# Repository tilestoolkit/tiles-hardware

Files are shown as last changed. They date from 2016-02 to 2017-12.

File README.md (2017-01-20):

# IoT Squares 

Squares are tiny stickers with electronics that give superpowers to everyday objects. They implement a set of physical interaction primitives.

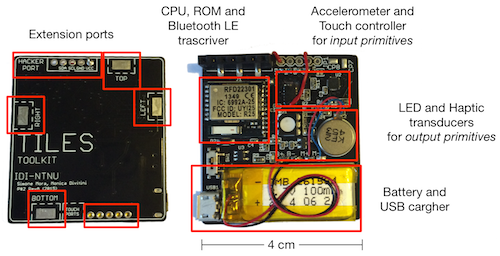
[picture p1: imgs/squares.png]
Squares modules


Squares are part of Tiles, an inventor toolbox to support the design and making of interactive objects for learning and play. For more information tilestoolkit.io

This work is licensed under a [Creative Commons Attribution-ShareAlike 4.0 International License](https://creativecommons.org/licenses/by-sa/4.0/).

## Prototypes History

### Prototype 1
Designed by Norwegian Creation, March 2015

### Prototype 2 Rev A
Designed by Simone Mora, PCB manufacturing and partial assembly from Seeedstudio Fusion Service, November 2015
#### Note: 
* Bug in board design, shortcut between VDD and SDA lines

### Prototype 2 Rev B
Designed by Simone Mora, never produced.
#### Note: 
* Fixed Rev A bugs

### Prototype 2 Rev C
Designed by Simone Mora, PCB manufacturing and partial assembly from Seeedstudio Fusion Service, April 2016
#### Note: 
* Removed touch controller MPR121
* Swapped components no longer available from Seed CPL

### Prototype 2 Rev D
Designed by Simone Mora, PCB manufacturing and partial assembly from Macrofab, November 2016
#### Note:
* Moved from SMD to DIP programming header
* Swapped components not available on Macrofab common parts library
* Added Seeed GROVE I2C connector

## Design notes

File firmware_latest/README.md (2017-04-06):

# Tiles DEVICE

## Notes
- When programming a Square Prototype 2 Rev D (RED Square) the ON/OFF switch must be put on OFF.
- Set in the code the type of Square module you have. For RFDUINO-shield-based modules set the *IS_SHIELD* variable on *TRUE*. For Prot#2 RevD module set the *COMMON_ANODE* to *true*

## API for Tiles DEVICE
### Events
| ID | Name | Parameter 1 | Parameter 2 | Implemented | Comments |
|----|---|---|---|---|---|
|Tile_XX | tap | single, double |  | yes | |
| | tilt | | | yes| |
| | shake  | | | yes| |
| | rotate | clock, c_clock | | yes | clockwise and counter clockwise |
| | drop | | | no | free fall event |
| | lift | | | no |  |
| | proximity | | | no | to be implemented with capacitive touch |

#### Example

Event generated when one Tiles is tapped twice
```javascript
"Tile_XX,tap,double"
```

### Commands
<table>
    <tr>
        <th>ID</th>
        <th>Name</th>
        <th>Parameter1</th>
        <th>Parameter2</th>
        <th>Implemented</th>
        <th>Comments</th>
    </tr><tr>
        <td>Tile_XX,</td>
        <td>led,</td>
        <td>off</td>
        <td>-</td>
        <td>yes</td>
        <td></td>
    </tr><tr>
        <td></td>
        <td></td>
        <td>on,</td>
        <td>red, green, blue, white</td>
        <td>yes</td>
        <td></td>
    </tr><tr>
        <td></td>
        <td></td>
        <td>on,</td>
        <td>{HEX}</td>
        <td>yes</td>
        <td>example: FF00FF=pink</td>
    </tr><tr>
        <td></td>
        <td></td>
        <td>blink,</td>
        <td>red, green, blue, white</td>
        <td>yes</td>
        <td></td>
    </tr><tr>
        <td></td>
        <td></td>
        <td>blink,</td>
        <td>{HEX}</td>
        <td>yes</td>
        <td></td>
    </tr><tr>
        <td></td>
        <td></td>
        <td>fade,</td>
        <td>red, green, blue, white</td>
        <td>only blue color implemented</td>
        <td></td>
    </tr><tr>
         <td></td>
         <td>haptic,</td>
         <td>long</td>
         <td>-</td>
         <td>yes</td>
         <td>long vibration</td>
     </tr><tr>
         <td></td>
         <td></td>
         <td>burst</td>
         <td>-</td>
         <td>yes</td>
         <td>short vibration</td>
     </tr>
</table>

#### Example
Turn on LED with color RED on 'Tile_XX' send command:
```javascript
"Tile_XX,led,on,red"
```
or use HEX
```javascript
"Tile_XX,led,on,FF0000"
```

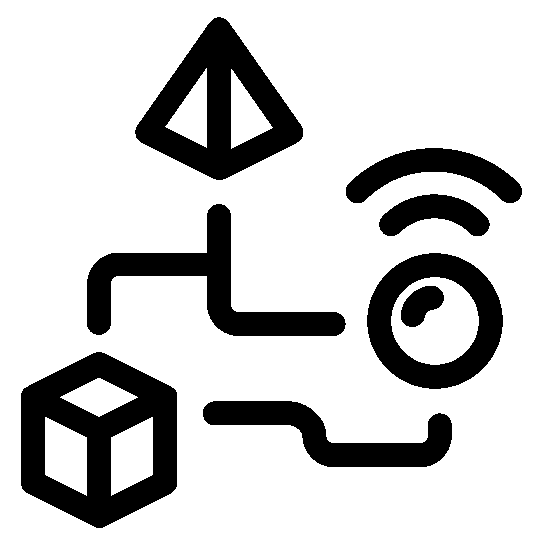
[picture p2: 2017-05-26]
Dock P1RB/imgs/noun_143916_cc.bmp

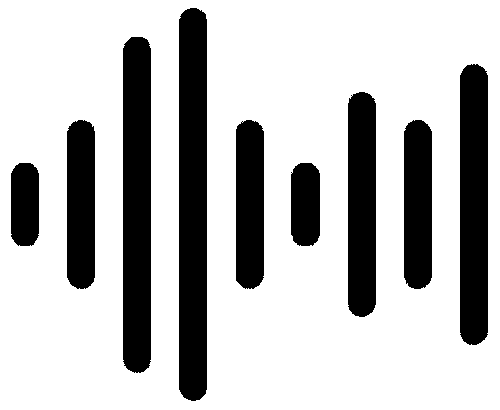
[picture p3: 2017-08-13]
Prototype 3 RevB/imgs/digi.bmp

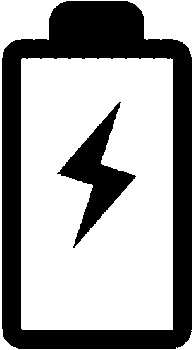
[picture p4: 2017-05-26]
Dock P1RB/imgs/battery.bmp

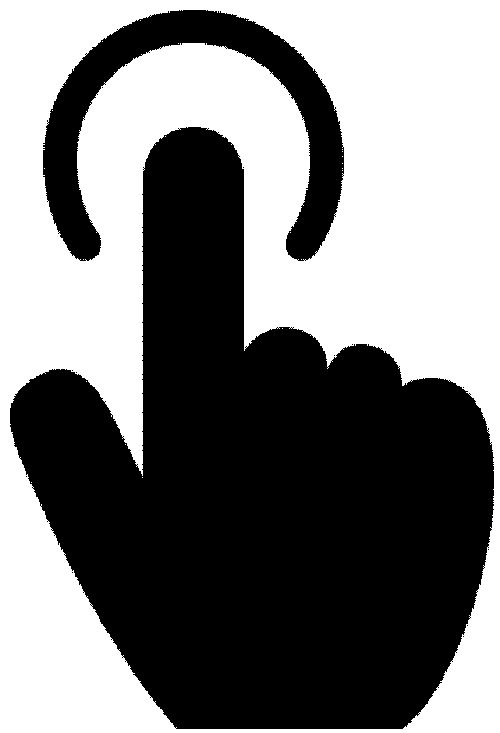
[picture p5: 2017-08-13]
Prototype 3 RevB/imgs/touch.bmp

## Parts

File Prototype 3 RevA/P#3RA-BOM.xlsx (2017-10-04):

BOM Tiles Prototype 3
Category | Quantity | Supplier reference (mouser) | References | Value | PCB Package | Reference | Supplier reference (mouser) | Supplier | Price | Price total
Condensator | 4 | 963-TMK107B7105KA-T | C1, C6, C7, C8 | 1uF | 0603 | TMK107B7105KA-T | 963-TMK107B7105KA-T | mouser | 1.2
Condensator | 1 | 81-GRM39X104K25 | C2 | 100nF | 0603 | GRM188R71E104KA01D | 81-GRM39X104K25 | mouser | 0.33
Condensator | 1 | 81-GRM188R61C106MA3D | C5 | 10uF | 0603 | GRM188R61C106MA73D | 81-GRM188R61C106MA3D | mouser | 1.65
Resistor | 5 | 667-ERJ-1GEJ103C | R1, R2, R3, R4, R7 | 10K | 0603 | 603-AF0603JR-0710KL | 603-AF0603JR-0710KL | mouser | 1.65
Resistor | 1 | 71-CRCW0603-100K-E3 | R5 | 100K | 0603 | CRCW0603100KFKEA | 71-CRCW0603-100K-E3 | mouser | 0.4
Resistor | 1 | 603-RC0603JR-07330RL | R6 | 330 | 0603 | RC0603JR-07330RL | 603-RC0603JR-07330RL | mouser | 0.7
Resistor | 1 | 667-ERJ-3GEYJ102V | R8 | 1K | 0603 | 667-ERJ-3GEYJ102V | 667-ERJ-3GEYJ102V | mouser | 0.1
Diodes | 1 | 78-1N4148W-G3-08 | D1 | 40V-50MA | SOD-123 | 1N4148WFL-G3-08 | 78-1N4148W-G3-08 | mouser | 1.54
Diodes | 1 | 667-LNJ037X8ARA | STAT | withe | LED0603 | LNJ037X8ARA | 667-LNJ037X8ARA | mouser | 3.56
Transistor | 1 | 726-MMBT3904LT1HTSA1 | U2 | MMBT3904 | SOT-23-3 | MMBT3904LT1HTSA1 | 726-MMBT3904LT1HTSA1 | mouser | 1.38
IC | 1 | 579-CAP1188-1-CP-TR | CAP1188 | CAP1188-1-CP-TR | QFN24_4MM_SMSC | CAP1188-1-CP-TR | 579-CAP1188-1-CP-TR | mouser | 10.94
IC | 1 | 595-DRV2605LDGSR | HAPTIC | DRV2605L | VSSOP-10 | DRV2605LDGSR | 595-DRV2605LDGSR | mouser | 32.74
IC | 1 | 584-ADXL345BCCZ-R | IMU | ADXL345BCCZ-RL | LGA24_3.5X3.1MM | 584-ADXL345BCCZ-R | 584-ADXL345BCCZ-R | mouser | 56.14
IC | 1 | 485-2686 | LED | WS2812B3535 | LED3535 | 1528-1541-ND | 485-2686 | mouser | 4
IC | 1 | 975-RFD77101 | SIMBLEE | RFD77101 | 45PIN LGA 0.5mm pitch | RFD77101 | 975-RFD77101 | mouser | 150
MISC | 1 | 490-CMT-4023S-SMT-TR | BUZZER | CMT-4023S-SMT-TR | 4x4mm 2 pin | CMT-4023S-SMT-TR | 490-CMT-4023S-SMT-TR | mouser | 25.6
MISC | 1 | 611-PTS810SJS250SMTR | SW | PTS810 SJS 250 SMTR LFS | TACT4.2MM | PTS810 SJS 250 SMTR LFS | 611-PTS810SJS250SMTR | mouser | 2.35
MISC | 1 | 712-BAT-HLD-001 | BATT1 | 712-BAT-HLD-001 | BAT-HLD-001 | 712-BAT-HLD-001 | 712-BAT-HLD-001 | mouser
Vibration motor | 1 | 713-316040001 | M+/M- |  |  |  | 713-316040001 | mouser | 9.71
MAGNETS
Solder paste |  |  |  |  |  |  |  | TOT | 303.99
Twizzers
BOM Dock P1
Category | Quantity | Supplier reference (mouser) | References | Value | PCB Package | Reference | Supplier reference (mouser) |  | Price | Price total
Condensator | 2 | 810-C3216X5R1C106M | C1,C2 | 10uF | 1206 | C3216X5R1C106M160AA | 810-C3216X5R1C106M | mouser
Resistor | 2 | 603-RC0805JR-07470RL | R1, R2 | 470 | 0805 | RC0805JR-07470RL | 603-RC0805JR-07470RL | mouser
Resistor | 1 | 603-RC0805FR-0710KL | R3 | 10K | 0805 | 603-RC0805FR-0710KL | 603-RC0805FR-0710KL | mouser
Diodes | 1 | 859-LTST-C171CKT | C | RED | CHIPLED_0805 | LTST-C171CKT | 859-LTST-C171CKT | mouser
Diodes | 1 | 859-LTST-C171GKT | R | GREEN | CHIPLED_0805 | LTST-C171GKT | 859-LTST-C171GKT | mouser
IC | 1 | 579-MCP73831T-2ACIOT | U1 | MCP73831T-2ACI/OT | SOT23-5 | MCP73831T-2ACI/OT | 579-MCP73831T-2ACIOT | mouser
MISC | 1 | 538-90147-1107 | J1 | MF-CON-2.54mm-01x07 | PTH_2.54MM_01X07 |  | 538-90147-1107 | mouser
MISC | 1 | 538-90147-1105 | J2 | MF-CON-2.54mm-01x05 | PTH_2.54MM_01X05 |  | 538-90147-1105 | mouser
MAGNETS

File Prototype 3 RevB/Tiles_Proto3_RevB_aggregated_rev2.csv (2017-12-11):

Parts | Qty | Value | MPN | HOUSEPART | Device | Package | Parts | Description | DIELECTRIC | HOUSEPART | MPN | POPULATE | PROD_ID | TOLERANCE | URL | VALUE | VOLTAGE | WATTAGE
C2, C11 | 2 | 0.1uF | MF-CAP-0603-0.1uF | yes | CAPACITOR_NP_0603 | C0603 | C2, C11 | Library: MF_Passives |  |  |  | 1
R5, R9, R10 | 3 | 100K | MF-RES-0603-100K | yes | RESISTOR_0603 | R0603 | R5, R9, R10 | Library: MF_Passives |  |  |  | 1
R1, R2, R3, R4, R7, R11 | 6 | 10K | MF-RES-0603-10K | yes | RESISTOR_0603 | R0603 | R1, R2, R3, R4, R7, R11 | Library: MF_Passives |  |  |  | 1
C3, C5, C9, C10 | 4 | 10uF | MF-CAP-1206-10uF | yes | CAPACITOR_NP_1206 | C1206 | C3, C5, C9, C10 | Library: MF_Passives |  |  |  | 1
L1 | 1 | 10uH | MF-IND-1210-10uH | yes | INDUCTOR_1210 | L1210 | L1 | Library: MF_Passives
R8 | 1 | 1K | MF-RES-0603-1K | yes | RESISTOR_0603 | R0603 | R8 | Library: MF_Passives |  |  |  | 1
C1, C6, C7 | 3 | 1uF | MF-CAP-0603-1uF | yes | CAPACITOR_NP_0603 | C0603 | C1, C6, C7 | Library: MF_Passives |  |  |  | 1
R13, R14 | 2 | 22 | MF-RES-0603-22 | yes | RESISTOR_0603 | R0603 | R13, R14 | Library: MF_Passives |  |  |  | 1
C4, C8 | 2 | 22pF | MF-CAP-0603-22pF | yes | CAPACITOR_NP_0603 | C0603 | C4, C8 | Library: MF_Passives |  |  |  | 1
R12 | 1 | 27 | MF-RES-0603-27 | yes | RESISTOR_0603 | R0603 | R12 | Library: MF_Passives |  |  |  | 1
X1 | 1 | 32.768 | ABS07-120-32.768KHZ-T |  | XTAL-3.2X1.5 | XTAL3215 | X1 | Low cost SMT crystals, no capacitors included
R6, R15 | 2 | 330 | MF-RES-0603-330 | yes | RESISTOR_0603 | R0603 | R6, R15 | Library: MF_Passives |  |  |  | 1
BUZZER | 1 | 4MBUZ | 490-CMT-4023S-SMT-TR |  | 4MBUZ | BUZPKG | BUZZER
U3 | 1 | ADXL345 | ADXL345BCCZ-RL |  | MOTION/POSITION-ADXL345BCCZ-RL(14P-5.0X3.0MM) | LGA14-0.8-5.0X3.0MM | U3 | 314080008 |  |  | ADXL345BCCZ-RL |  |  |  |  | ADXL345BCCZ-RL
U2 | 1 | AP2112 | AP2112K-3.3TRG1 |  | VREG_SOT23-5 | SOT23-5 | U2 | SOT23-5 Fixed Voltage Regulators
U4 | 1 | CAP1188 | CAP1188-1-CP-TR |  | CAP1188 | QFN24_4MM_SMSC | U4 | CAP1188 - Eight Channel Cap Touch Controller
Q1 | 1 | DMG3415U-7 | MF-DSC-SOT233-BSS84 | yes | MOSFET-P | SOT23-R | Q1 | P-Channel Mosfet
U5 | 1 | DRV2605L | DRV2605LDGST |  | DRV2605L | VSSOP-10 | U5 |  |  |  |  |  | IC-13504
D1 | 1 | MBR120 | MBR120LSFT1G |  | DIODE-SCHOTTKYSOD-123 | SOD-123 | D1
U1 | 1 | MDBT42Q | 317030213 |  | NRF52832_MODULE_MDBT42 | BLE_MODULE_RAYTAC_MDBT42 | U1 | MDBT42 - BLE Module (nRF52832 QFN)
D2 | 1 | MF-DIO-SOD123-1N4148 | MF-DIO-SOD123-1N4148 | yes | DIODES_1N4148_SOD-123 | SOD-123 | D2 | Library: MF_Discrete_Semiconductor |  | YES | MF-DIO-SOD123-1N4148 | 1 |  |  | https://factory.macrofab.com/part/MF-DIO-SOD123-1N4148 | MF-DIO-SOD123-1N4148
T2 | 1 | MF-DSC-SOT233-MMBT3904 | MF-DSC-SOT233-MMBT3904 | yes | NPN_BJTMMBT3904_SOT-23-3 | SOT-23-3 | T2 | Library: MF_Discrete_Semiconductor |  | YES | MF-DSC-SOT233-MMBT3904 | 1 |  |  | https://factory.macrofab.com/part/MF-DSC-SOT233-MMBT3904 | MF-DSC-SOT233-MMBT3904
BTL | 2 | MF-LED-0603-RED | MF-LED-0603-RED | yes | LED_SINGLE-0603-RED | LED0603 | BTL | Library: MF_LEDs |  | YES | MF-LED-0603-RED | 1 |  |  | https://factory.macrofab.com/part/MF-LED-0603-RED | MF-LED-0603-RED
STAT |  |  | LNJ037X8ARA |  |  |  | STAT
D3 | 1 | MF-LED-3228-RGB | MF-LED-3228-RGB | yes | LED_RGB_CA_PLCC4 | PLCC4 | D3 | Library: MF_LEDs |  | YES | MF-LED-3228-RGB | 1 |  |  | https://factory.macrofab.com/part/MF-LED-3228-RGB | MF-LED-3228-RGB
SW | 1 | MF-SW-TACT-4.2MM | MF-SW-TACT-4.2MM | yes | TACT_4.2MM | TACT4.2MM | SW | Library: MF_Switches |  | YES | MF-SW-TACT-4.2MM | 1 |  |  | https://factory.macrofab.com/part/MF-SW-TACT-4.2MM | MF-SW-TACT-4.2MM
Vibration motor
Battery
Header
magnets

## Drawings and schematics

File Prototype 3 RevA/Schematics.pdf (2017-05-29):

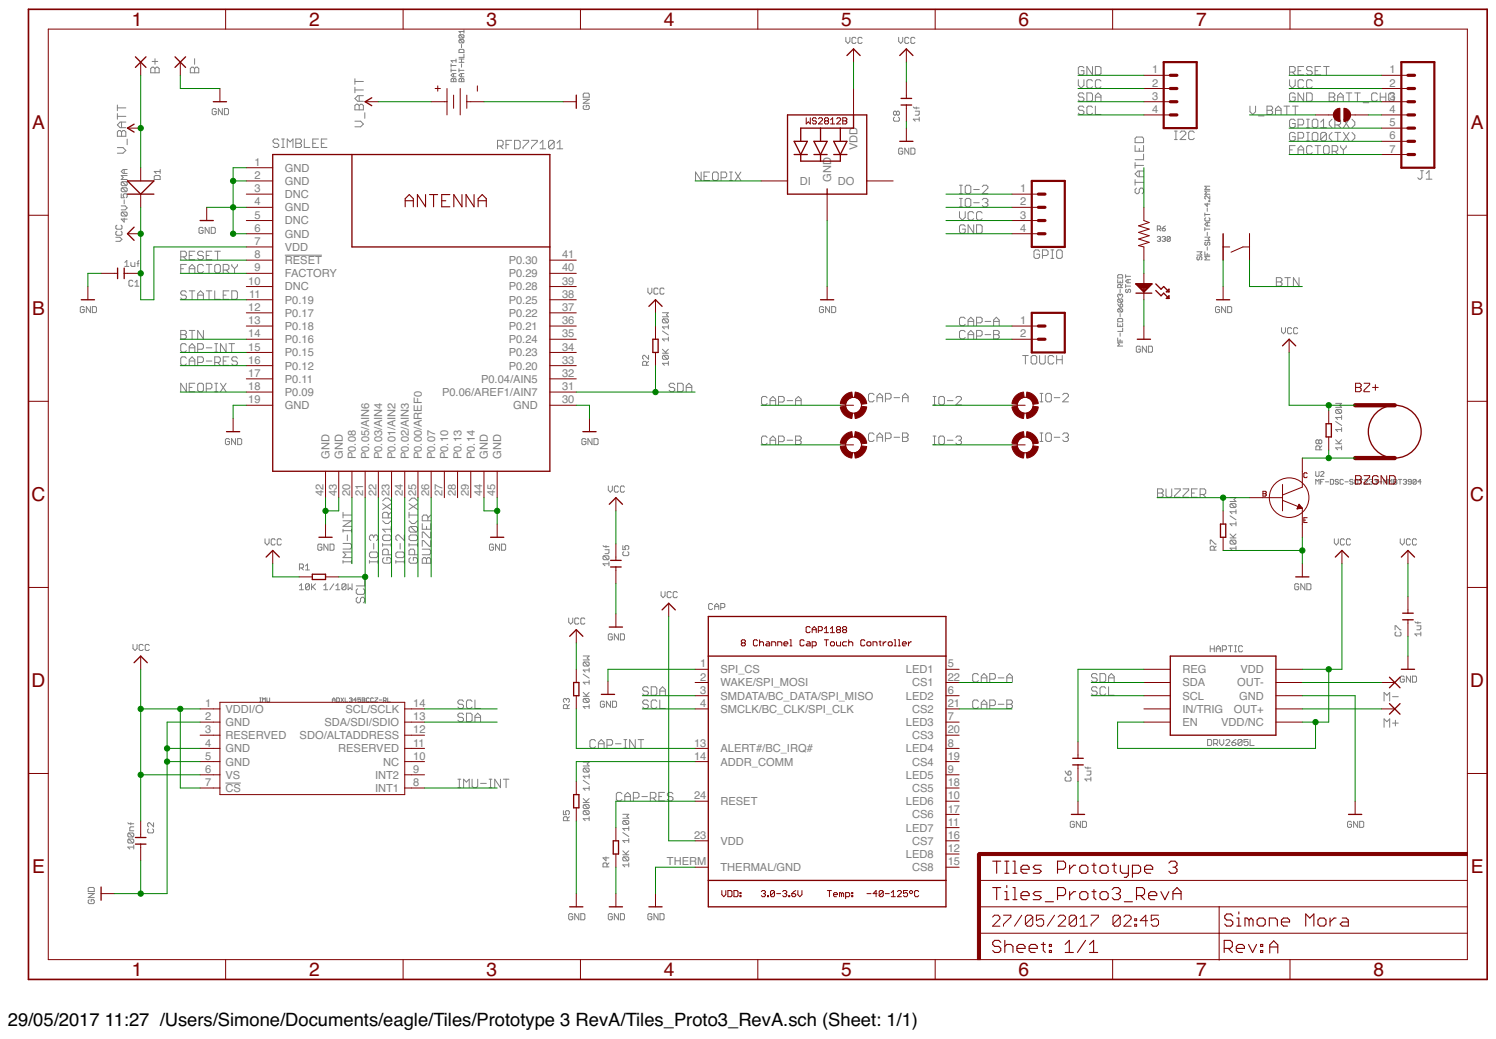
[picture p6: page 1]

OUT+ GND OUT- VDD

29/05/2017 11:27 /Users/Simone/Documents/eagle/Tiles/Prototype 3 RevA/Tiles_Proto3_RevA.sch (Sheet: 1/1)

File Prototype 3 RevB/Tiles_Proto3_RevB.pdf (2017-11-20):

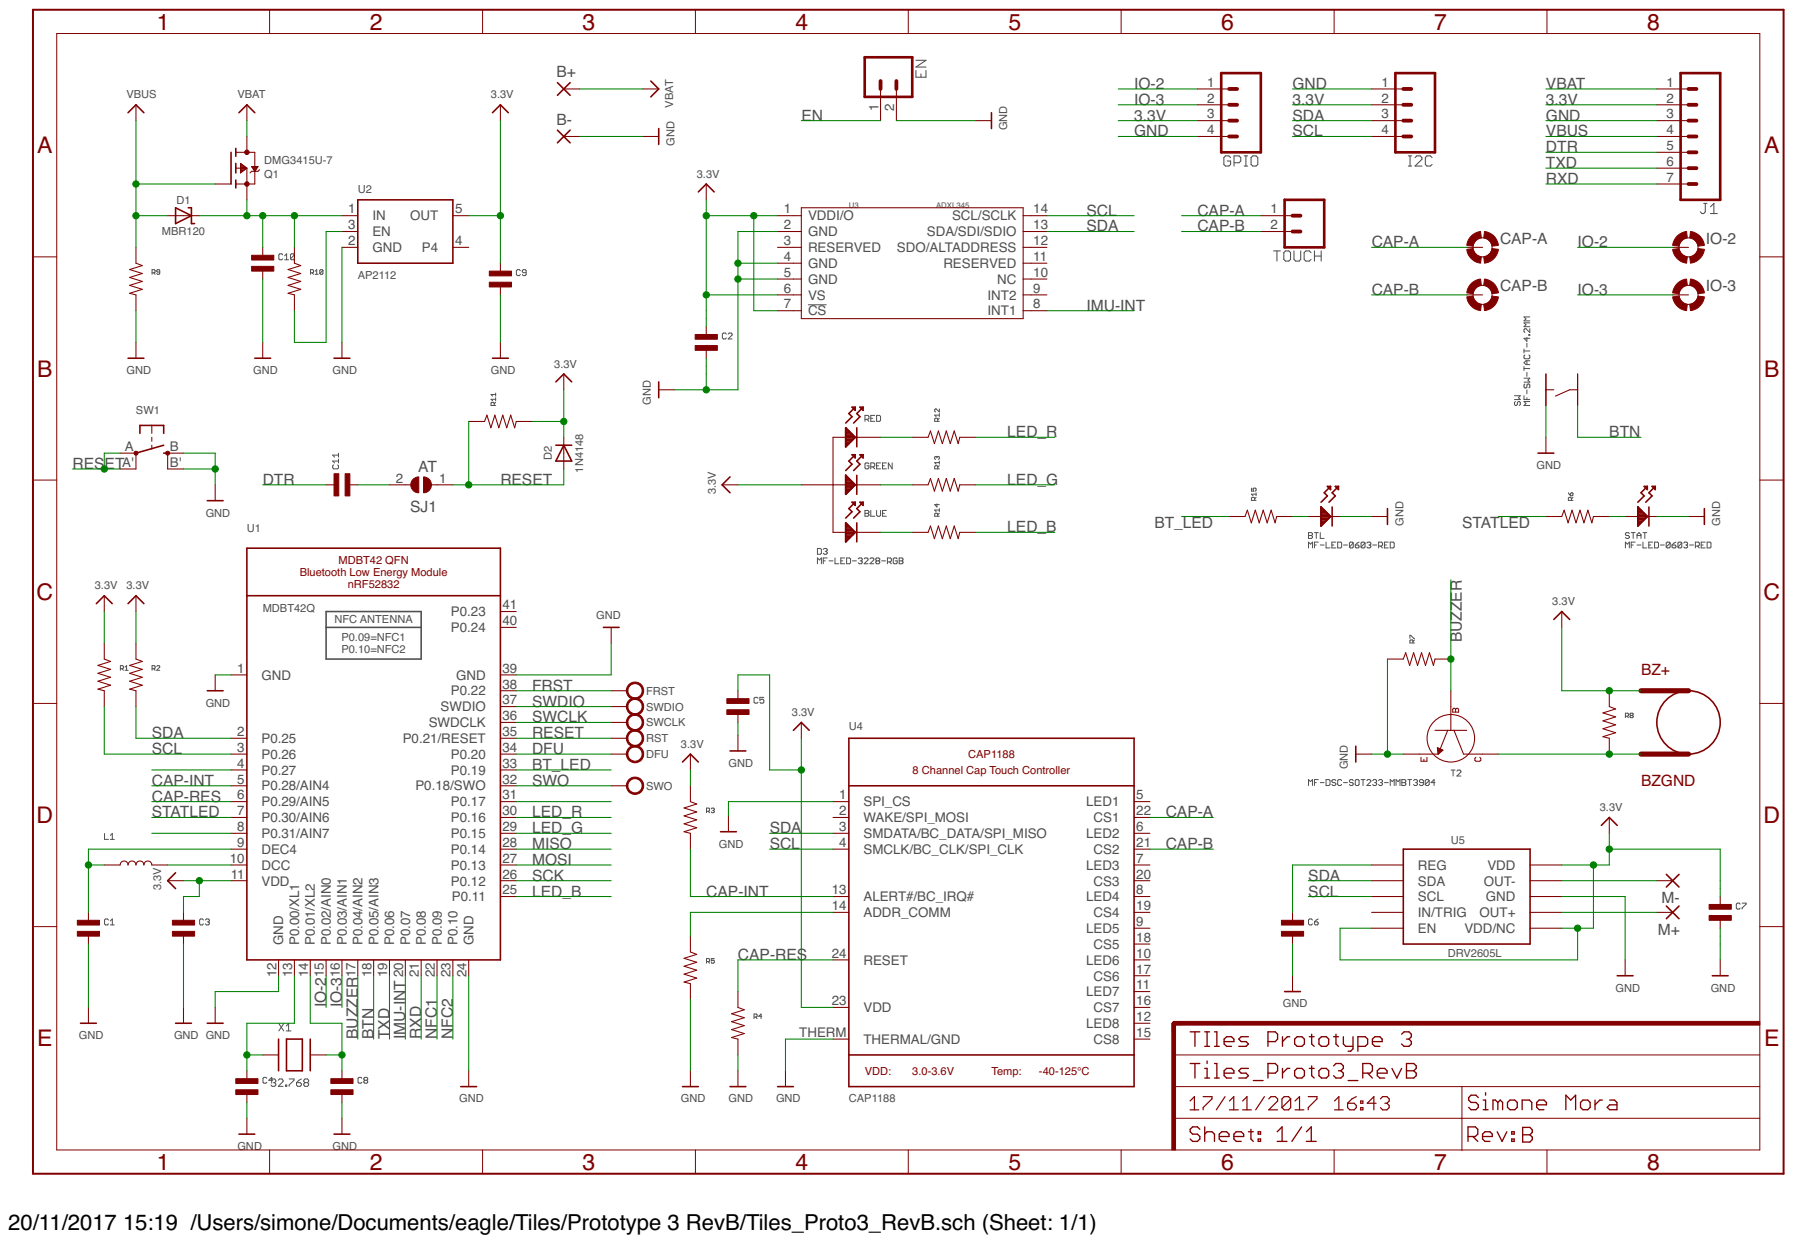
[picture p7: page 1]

Bluetooth Low Energy Module

8 Channel Cap Touch Controller

OUT+ GND OUT- VDD

CAP-RES | 24

20/11/2017 15:19 /Users/simone/Documents/eagle/Tiles/Prototype 3 RevB/Tiles_Proto3_RevB.sch (Sheet: 1/1)

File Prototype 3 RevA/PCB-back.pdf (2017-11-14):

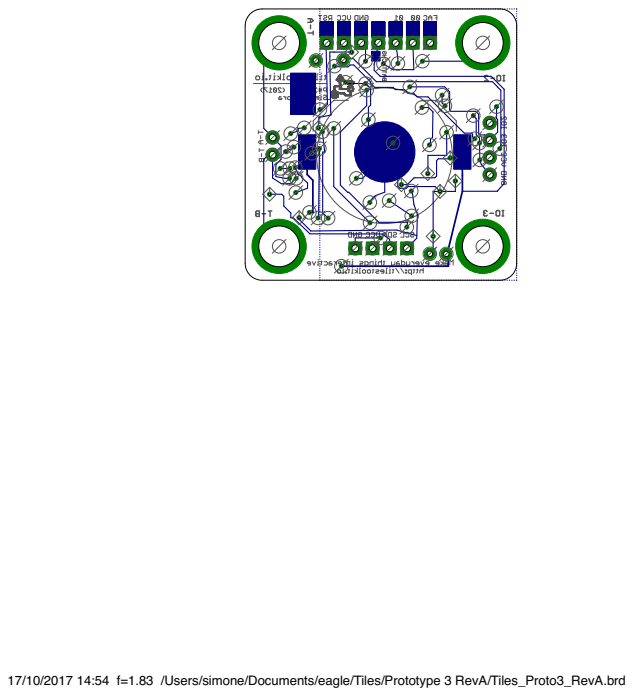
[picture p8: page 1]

17/10/2017 14:54 f=1.83 /Users/simone/Documents/eagle/Tiles/Prototype 3 RevA/Tiles_Proto3_RevA.brd

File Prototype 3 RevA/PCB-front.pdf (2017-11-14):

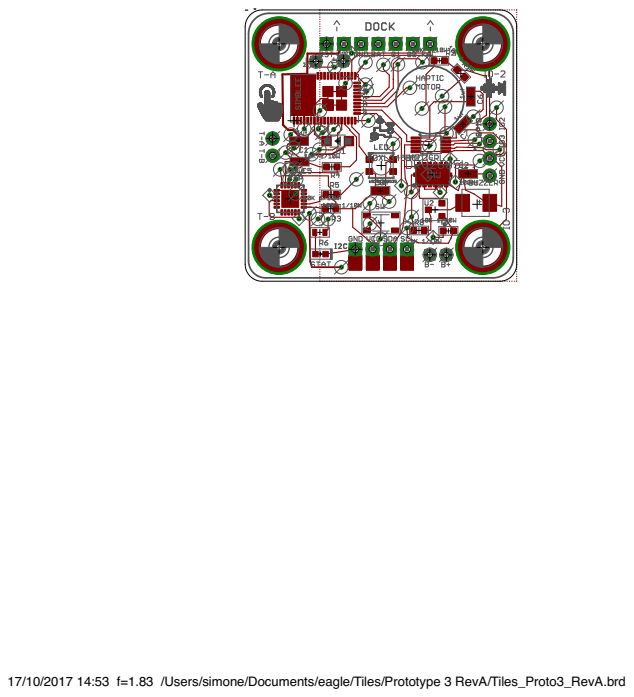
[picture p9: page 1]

17/10/2017 14:53 f=1.83 /Users/simone/Documents/eagle/Tiles/Prototype 3 RevA/Tiles_Proto3_RevA.brd

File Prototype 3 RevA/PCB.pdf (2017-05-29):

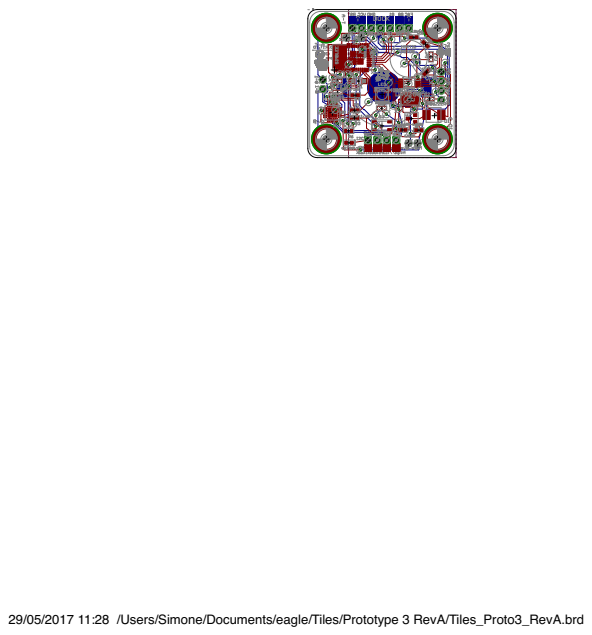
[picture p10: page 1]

29/05/2017 11:28 /Users/Simone/Documents/eagle/Tiles/Prototype 3 RevA/Tiles_Proto3_RevA.brd

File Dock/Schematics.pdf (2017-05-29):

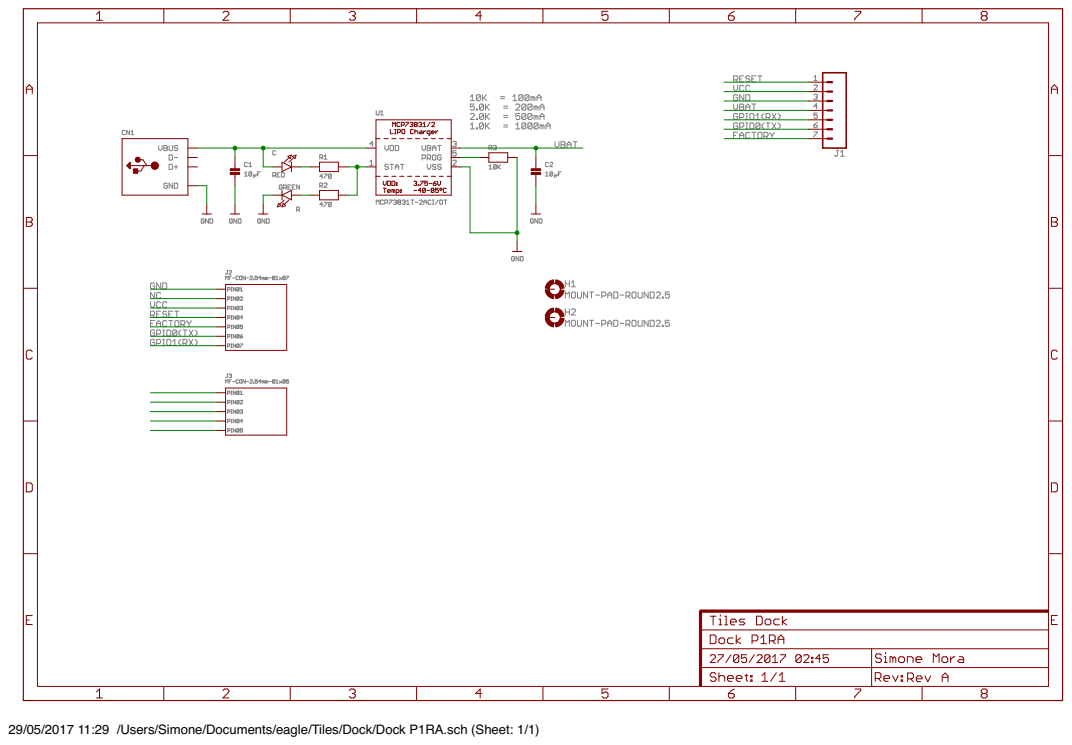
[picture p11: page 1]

29/05/2017 11:29 /Users/Simone/Documents/eagle/Tiles/Dock/Dock P1RA.sch (Sheet: 1/1)

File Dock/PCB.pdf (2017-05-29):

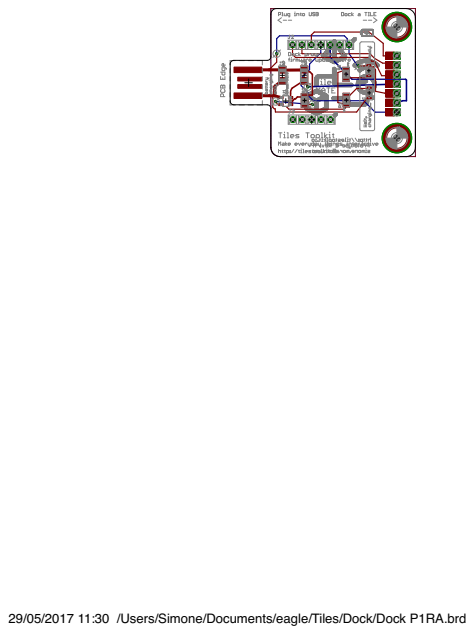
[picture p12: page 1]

29/05/2017 11:30 /Users/Simone/Documents/eagle/Tiles/Dock/Dock P1RA.brd

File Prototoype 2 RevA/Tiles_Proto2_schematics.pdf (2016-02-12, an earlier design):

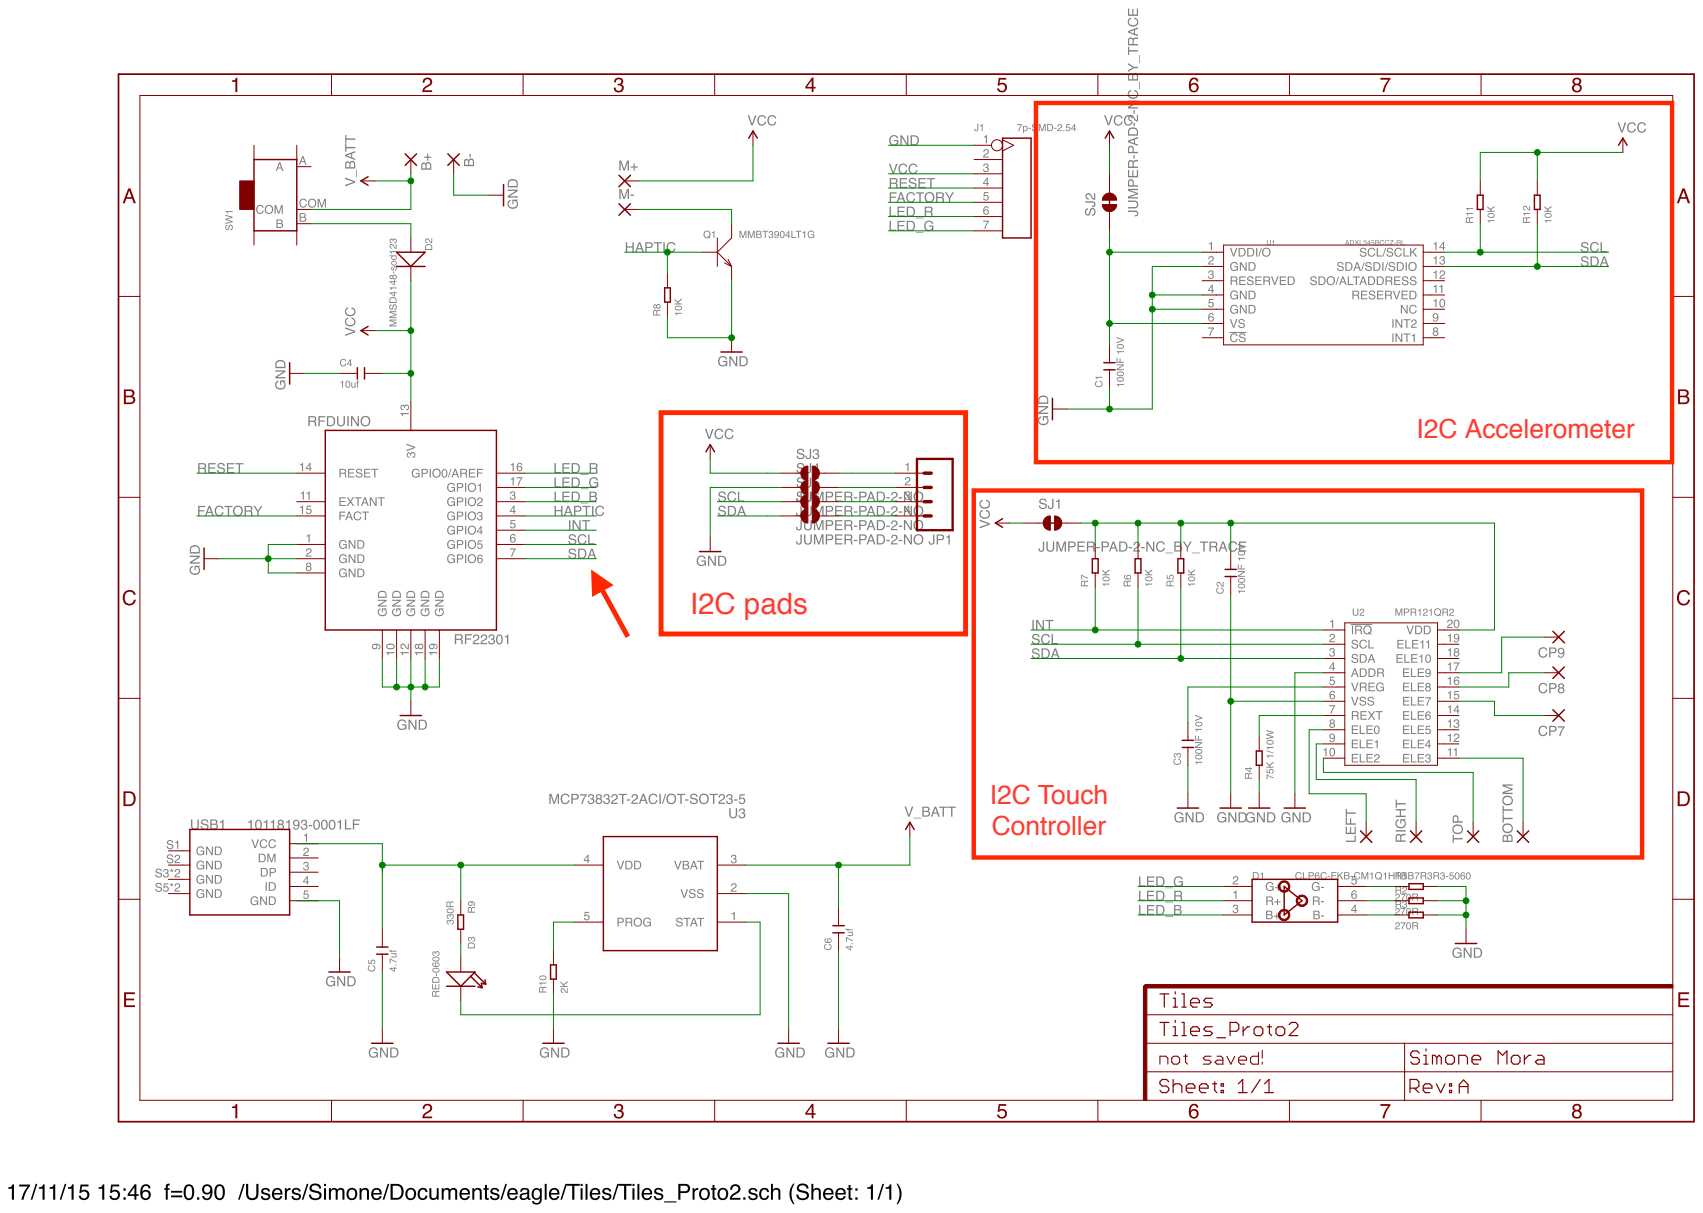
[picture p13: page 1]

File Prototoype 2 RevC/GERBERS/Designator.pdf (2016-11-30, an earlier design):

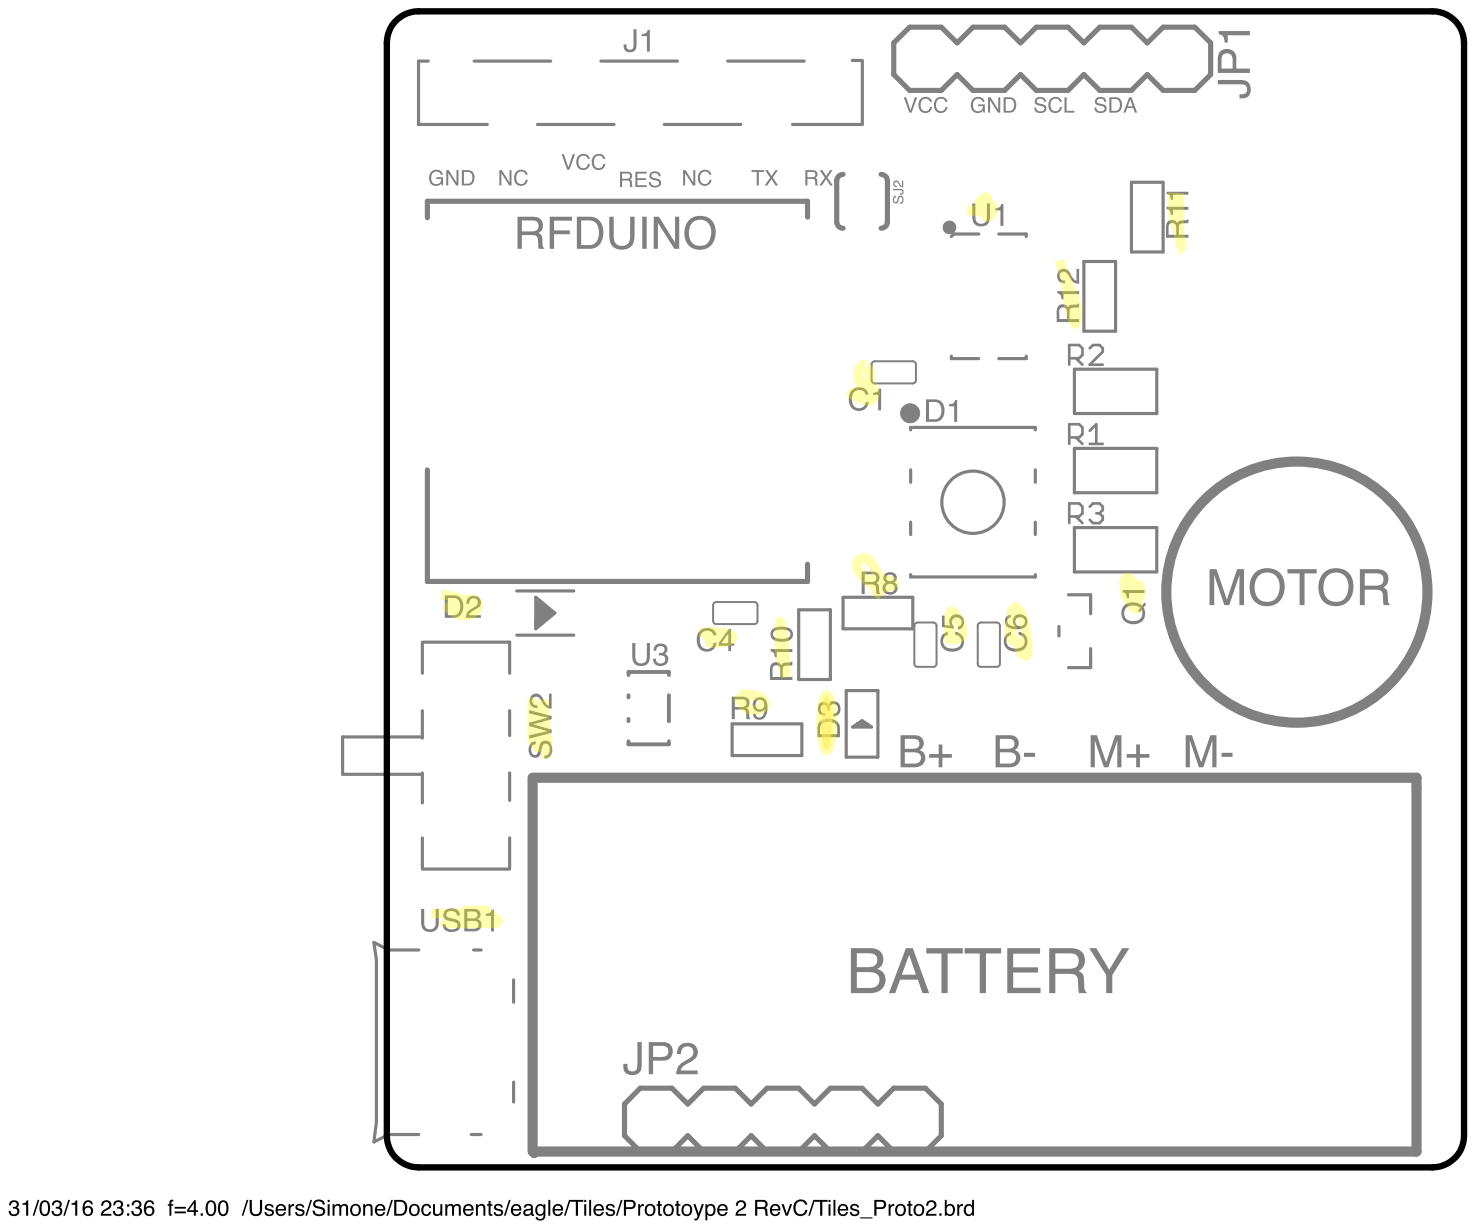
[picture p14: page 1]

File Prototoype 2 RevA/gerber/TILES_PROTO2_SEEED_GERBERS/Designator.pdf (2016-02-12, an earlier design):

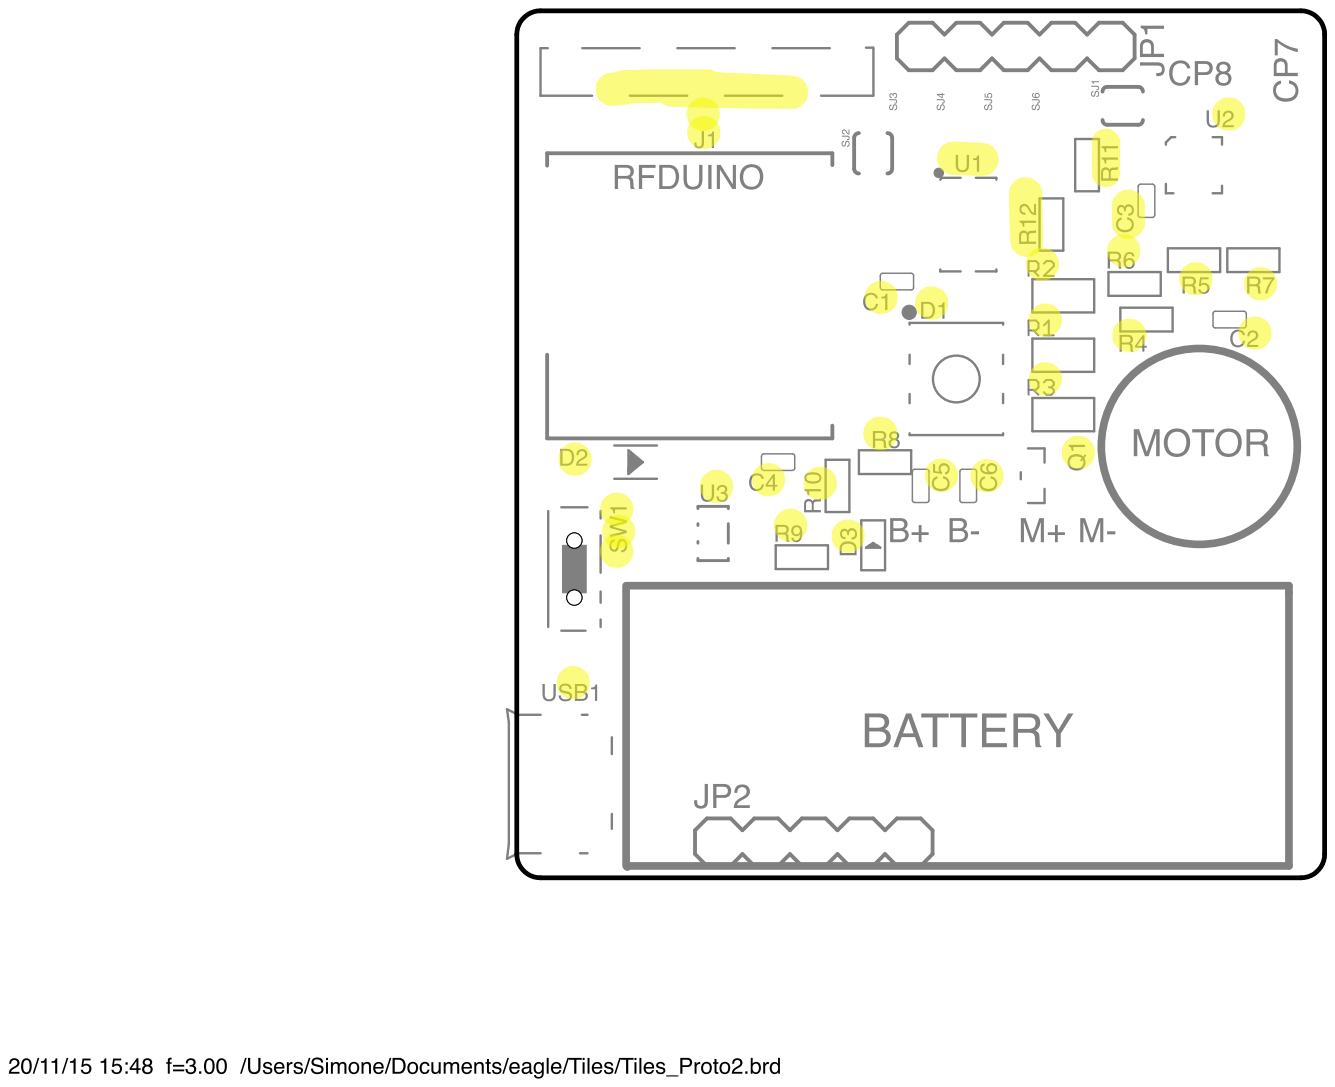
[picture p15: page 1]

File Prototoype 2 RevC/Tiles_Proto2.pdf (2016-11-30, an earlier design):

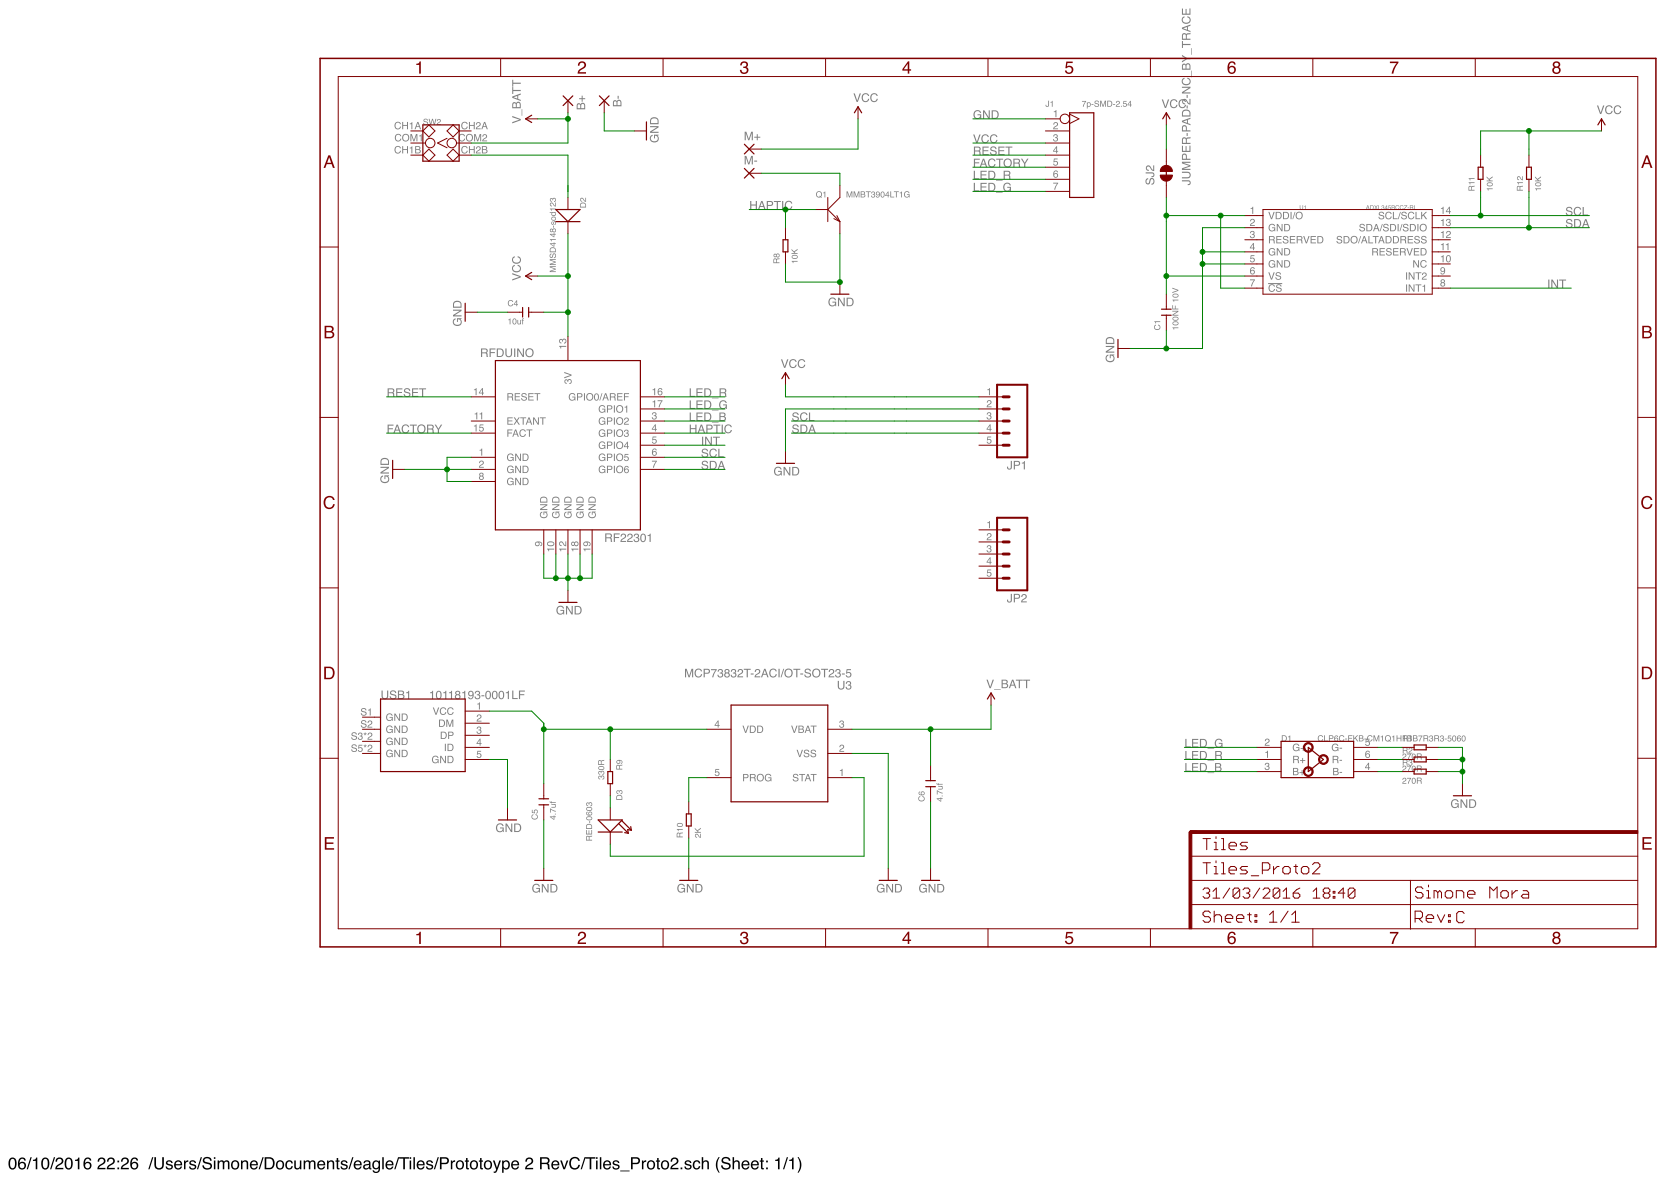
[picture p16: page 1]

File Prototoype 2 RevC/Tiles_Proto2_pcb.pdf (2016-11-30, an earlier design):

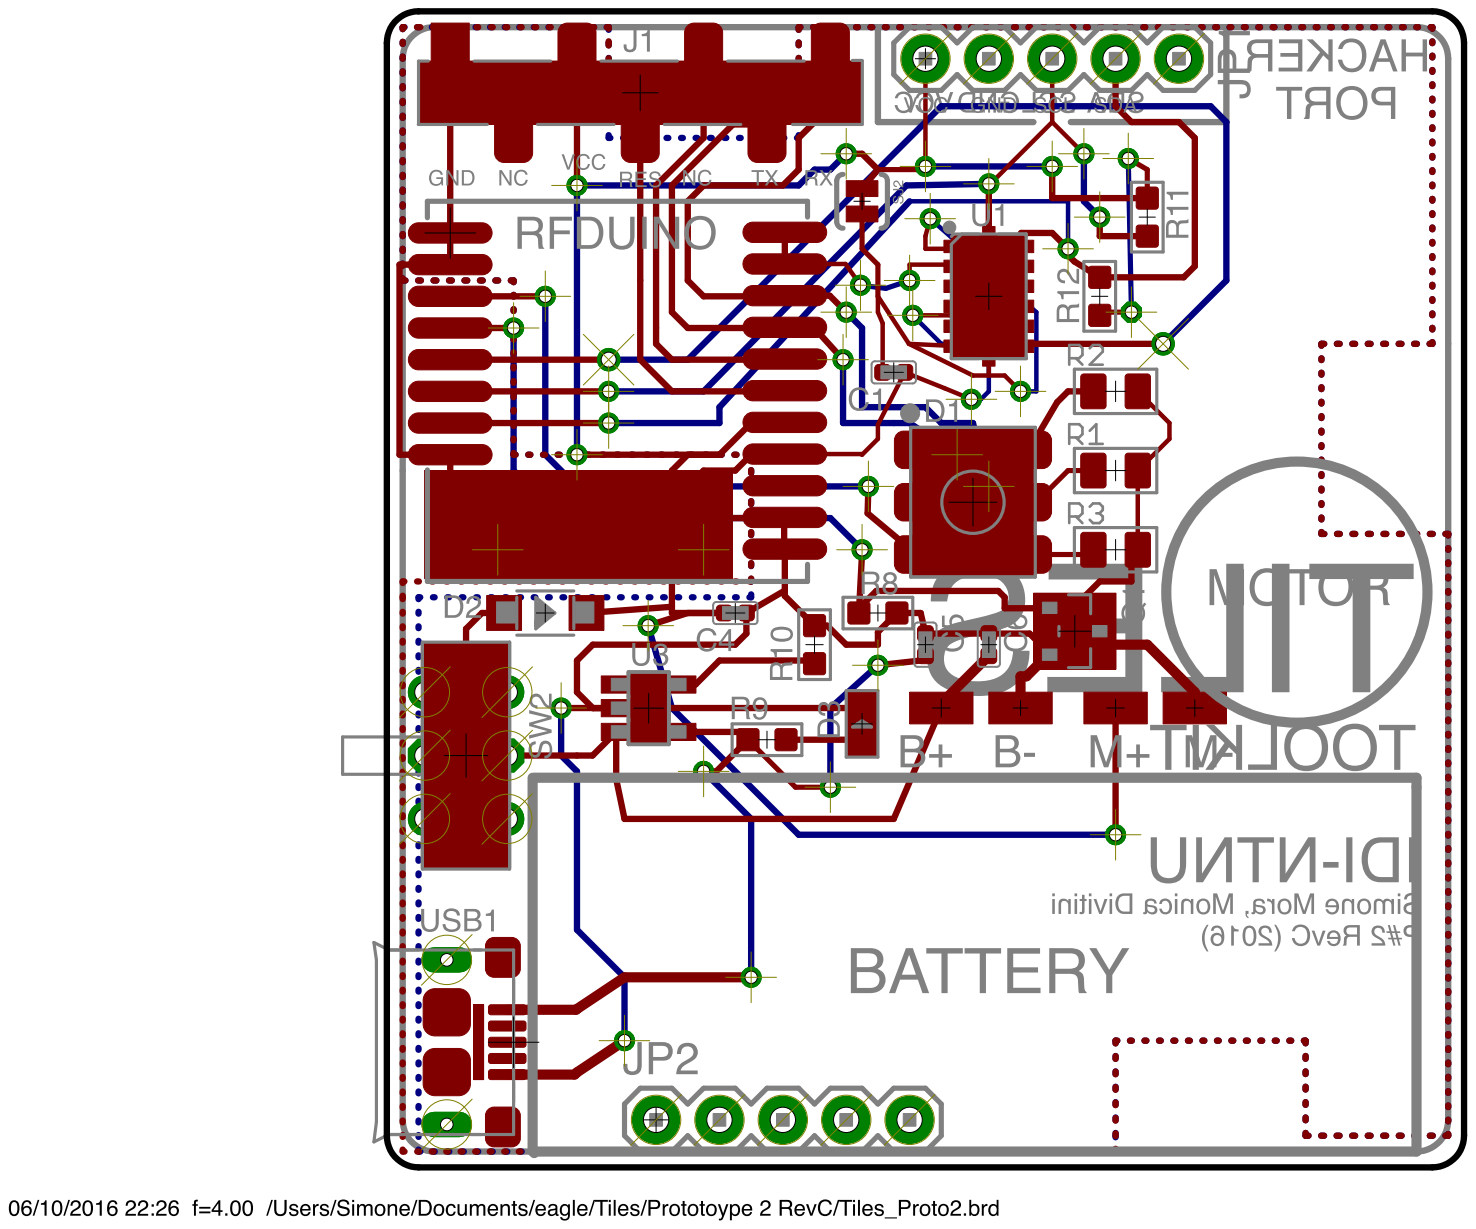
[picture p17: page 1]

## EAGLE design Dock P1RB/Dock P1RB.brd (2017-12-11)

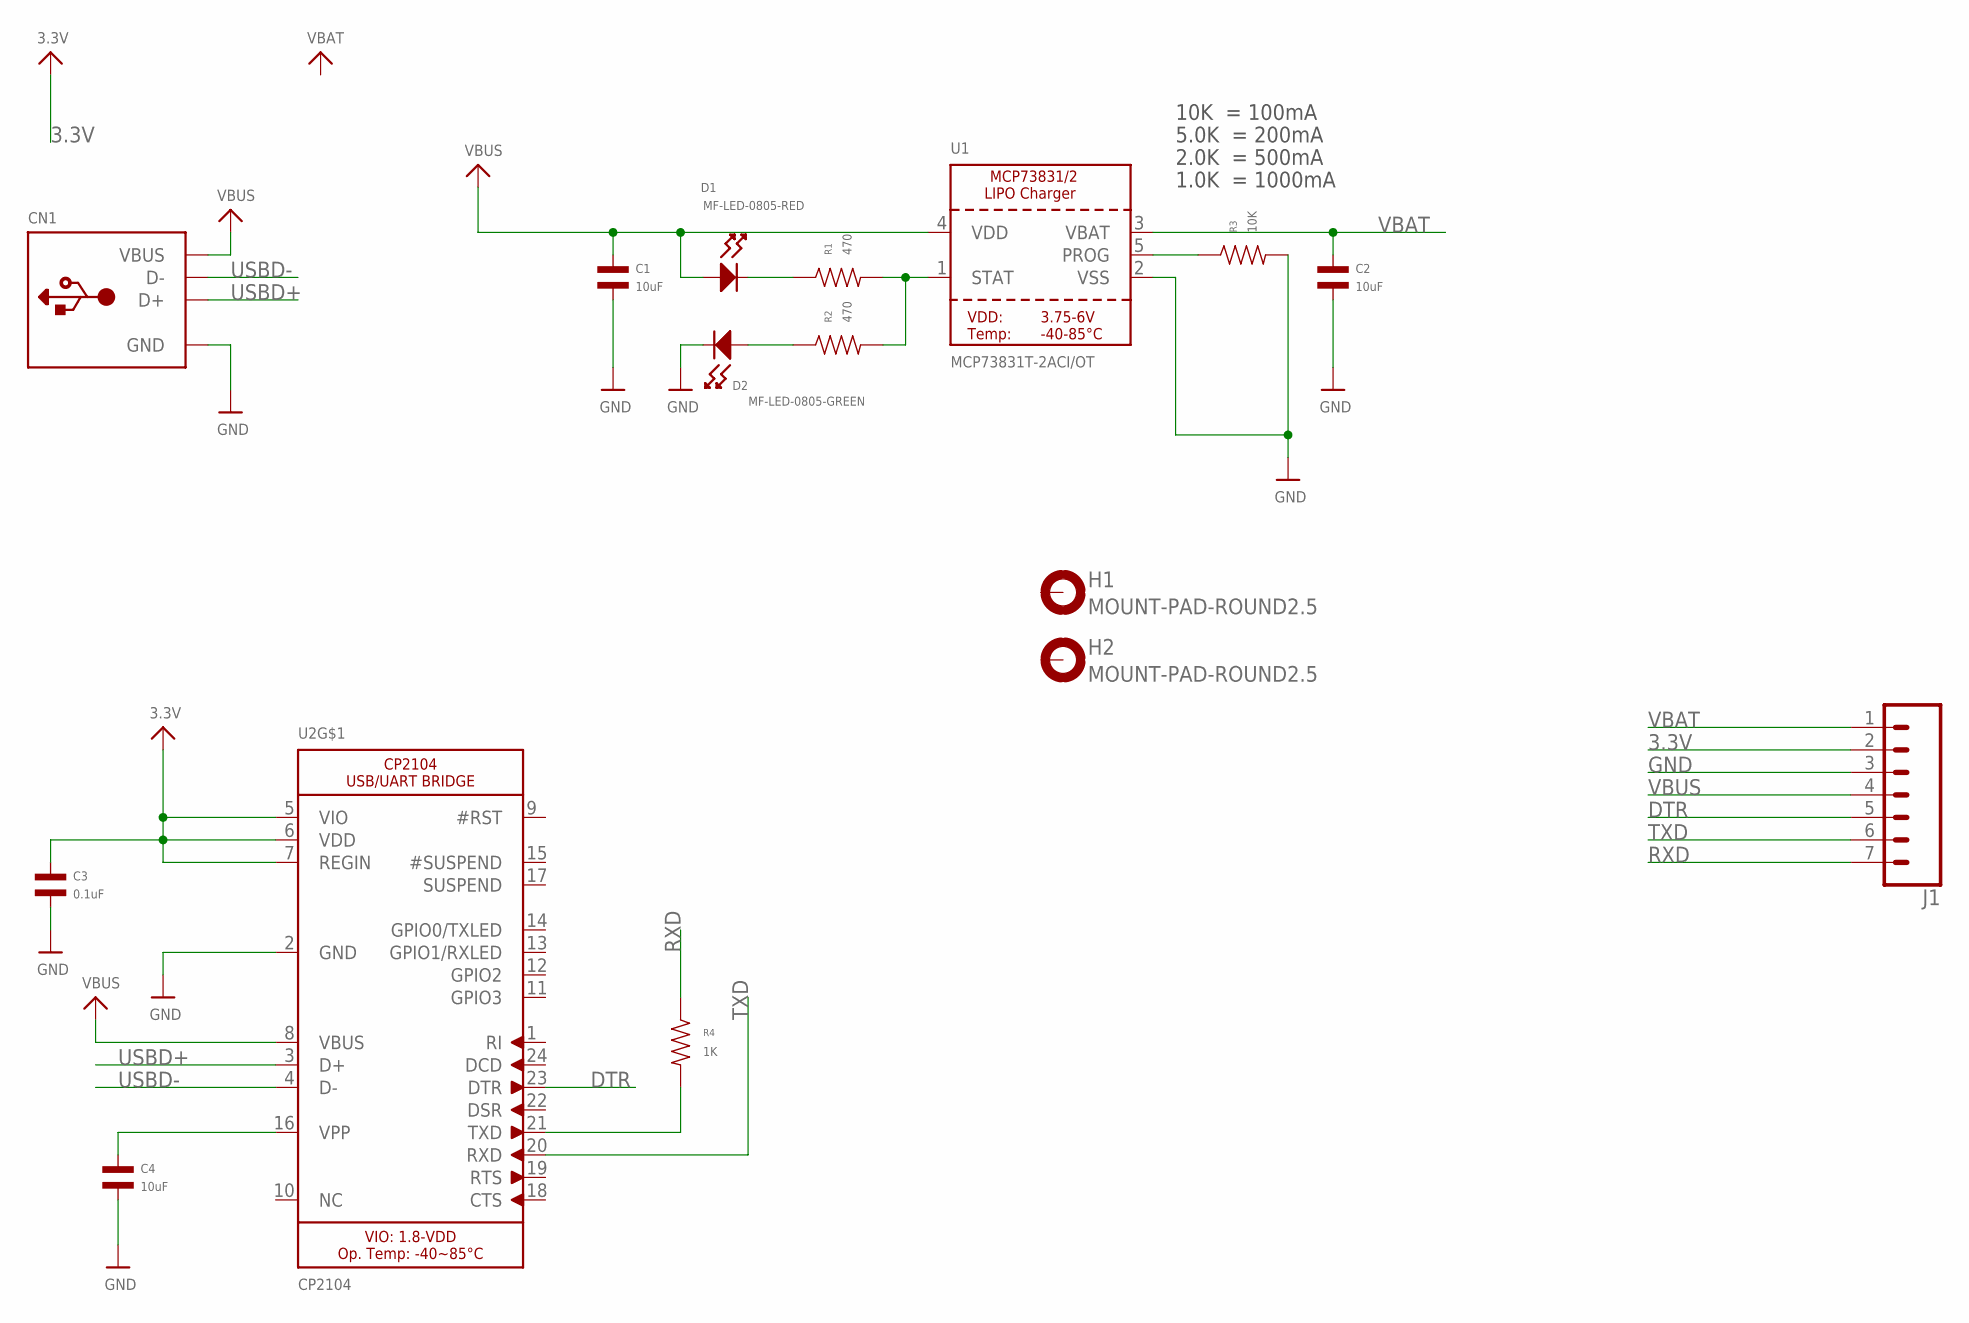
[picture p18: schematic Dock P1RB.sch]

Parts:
C1, C2, C4: 10uF; C1206; MPN MF-CAP-1206-10uF
C3: 0.1uF; C0603; MPN MF-CAP-0603-0.1uF
CN1: USB_TYPEAPCB; USBA_PCB
D1: MF-LED-0805-RED; LED0805
D2: MF-LED-0805-GREEN; LED0805
H1, H2: MOUNT-PAD-ROUND2.5; 2,5-PAD-SIM
J1: CONN_07; 1X07
R1, R2: 470; R0603; MPN MF-RES-0603-470
R3: 10K; R0603; MPN MF-RES-0603-10K
R4: 1K; R0603; MPN MF-RES-0603-1K
U1: MCP73831T-2ACI/OT; SOT23-5; MPN MCP73831T-2ACI/OT
U2: CP2104; QFN24_4MM_SMSC; MPN CP2104

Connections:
3.3V: C3.P$1, J1.2, U2.5 (VIO), U2.6 (VDD), U2.7 (REGIN)
DTR: J1.5, U2.23 (DTR)
GND: C1.P$2, C2.P$2, C3.P$2, C4.P$2, CN1.GND, D2.CATHODE, J1.3, R3.P$2, U1.2 (VSS), U2.2 (GND)
unnamed: D1.CATHODE, R1.P$1
unnamed: R1.P$2, R2.P$2, U1.1 (STAT)
unnamed: C4.P$1, U2.16 (VPP)
unnamed: R3.P$1, U1.5 (PROG)
unnamed: D2.ANODE, R2.P$1
unnamed: R4.P$2, U2.21 (TXD)
RXD: J1.7, R4.P$1
TP: U2.THERM (TP)
TXD: J1.6, U2.20 (RXD)
USBD+: CN1.USB_PLUS (D+), U2.3 (D+)
USBD-: CN1.USB_NEG (D-), U2.4 (D-)
VBAT: C2.P$1, J1.1, U1.3 (VBAT)
VBUS: C1.P$1, CN1.VCC (VBUS), D1.ANODE, J1.4, U1.4 (VDD), U2.8 (VBUS)

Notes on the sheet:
10K = 100mA
5.0K = 200mA
2.0K = 500mA
1.0K = 1000mA

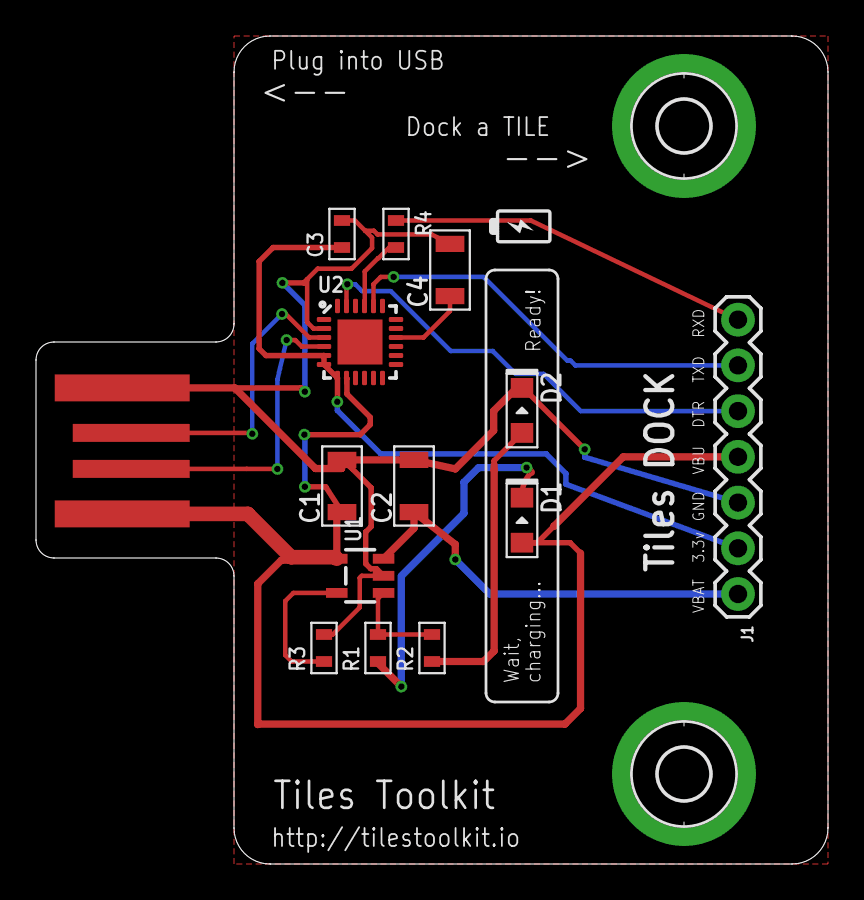
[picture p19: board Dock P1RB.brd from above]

Board: 2 copper layers, 44.0 x 46.0 mm, 16 parts (0 on the bottom side), 15 nets.

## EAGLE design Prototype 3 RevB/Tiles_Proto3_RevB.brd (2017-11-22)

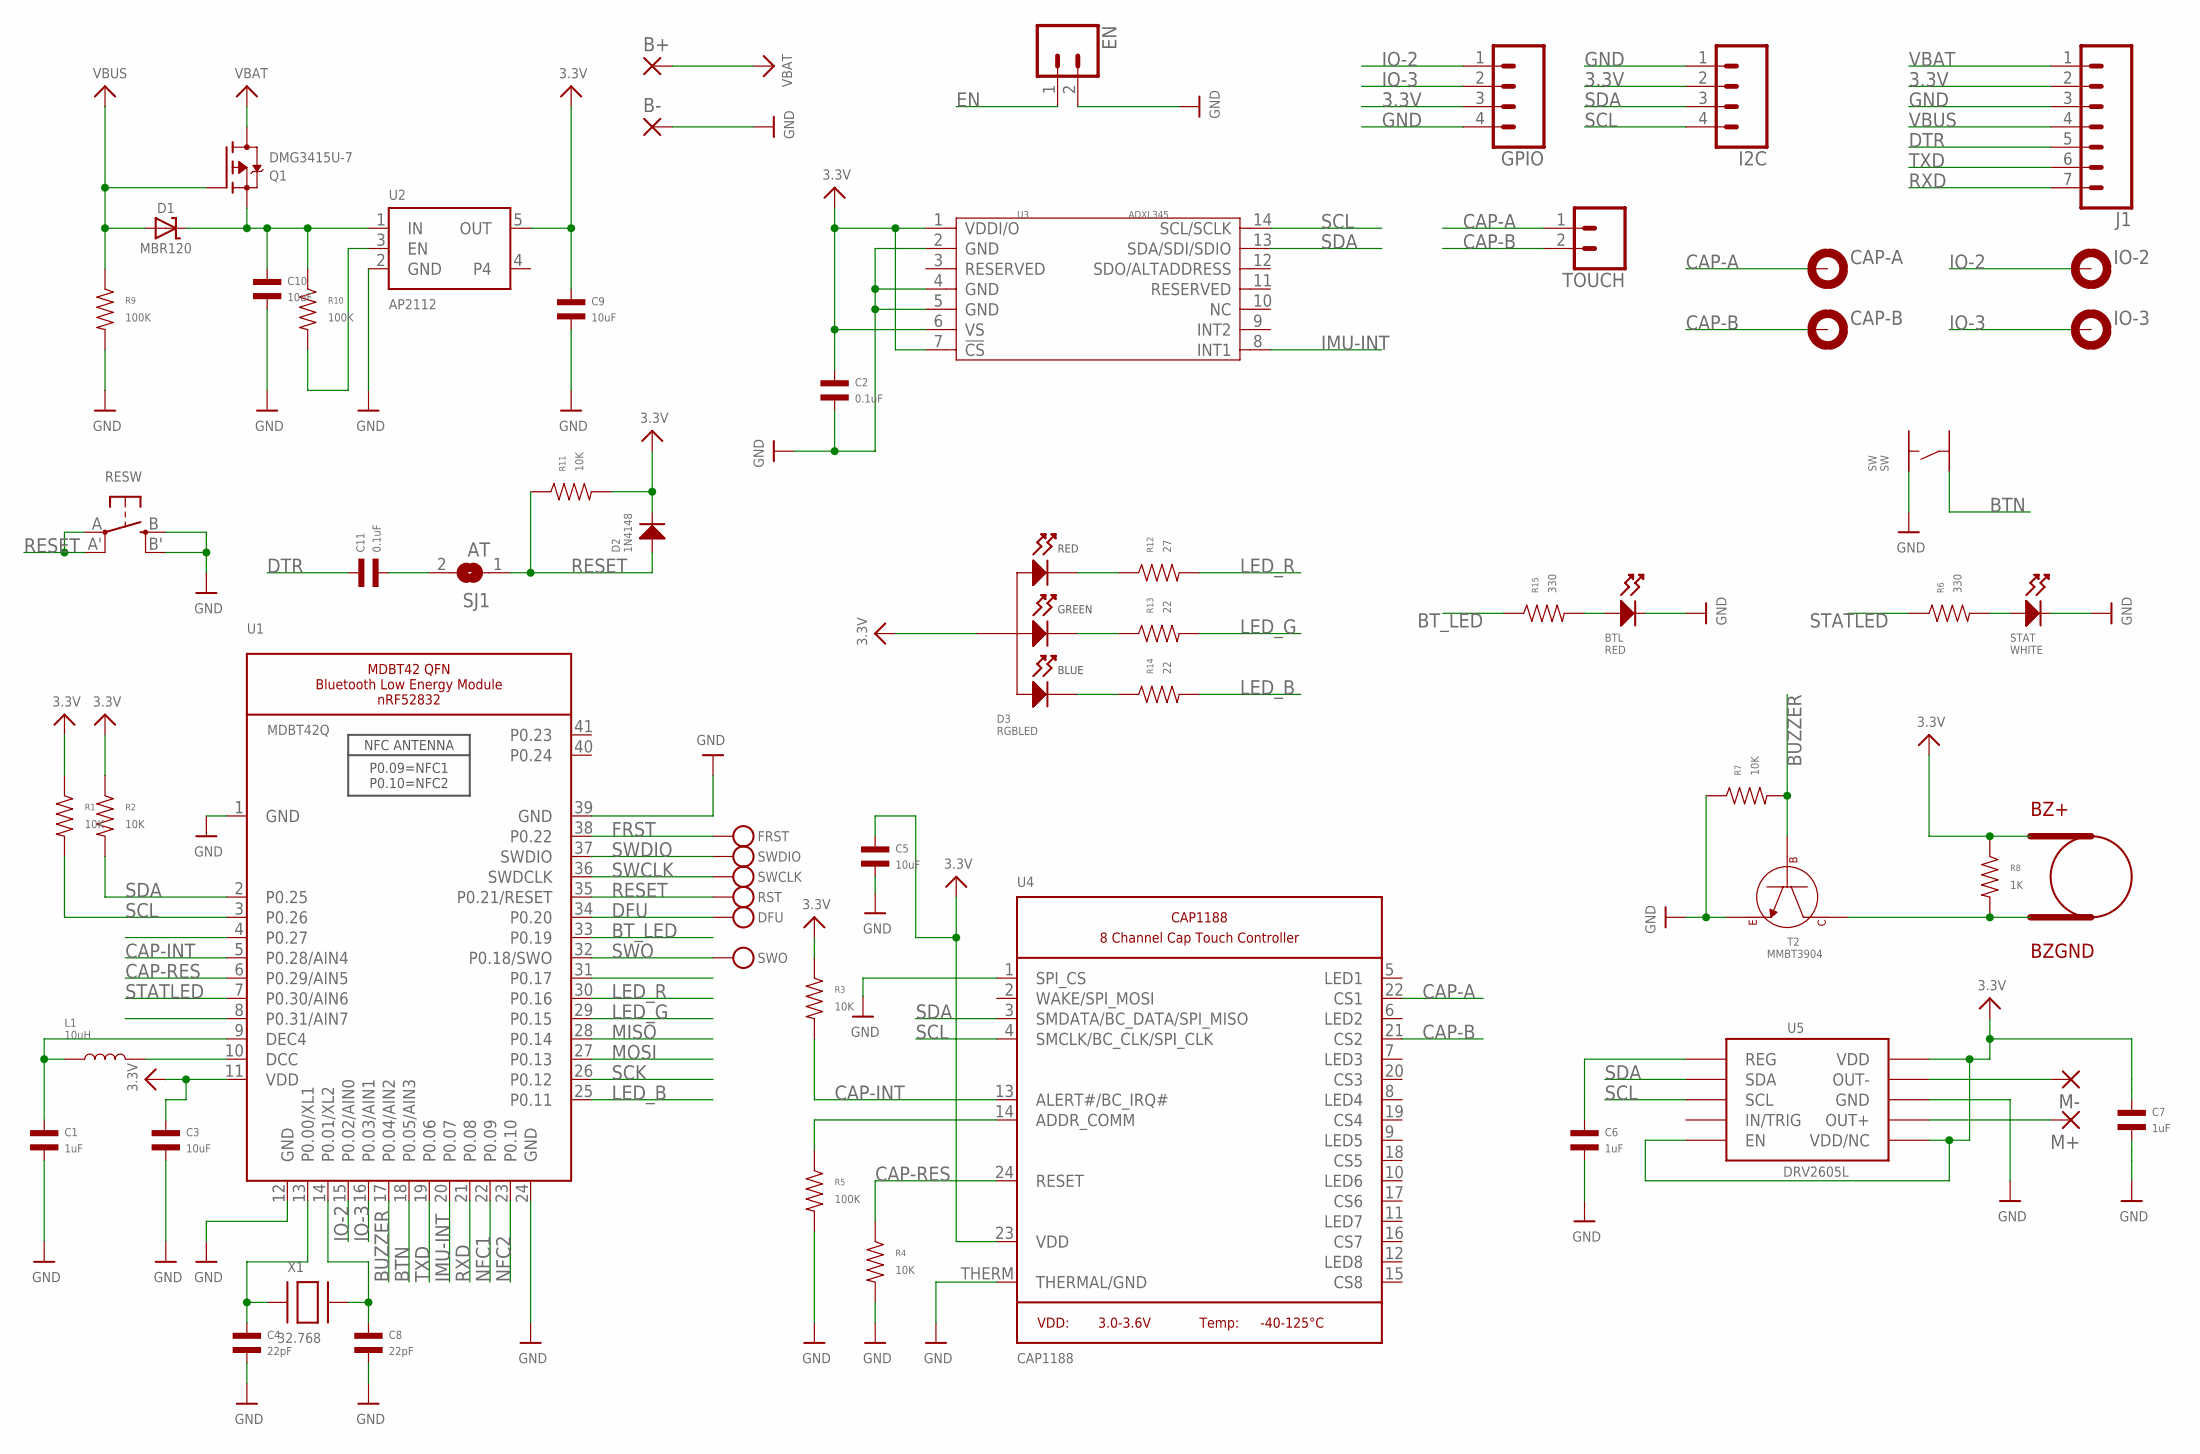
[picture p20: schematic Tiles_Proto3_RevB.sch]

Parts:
B+: SMD2; SMD1,27-2,54
B-: SMD2; SMD1,27-2,54
BTL: RED; LED0603
BUZZER: 4MBUZ; BUZPKG; MPN 490-CMT-4023S-SMT-TR
C1, C6, C7: 1uF; C0603; MPN MF-CAP-0603-1uF
C2, C11: 0.1uF; C0603; MPN MF-CAP-0603-0.1uF
C3, C5, C9, C10: 10uF; C1206; MPN MF-CAP-1206-10uF
C4, C8: 22pF; C0603; MPN MF-CAP-0603-22pF
CAP-A: MOUNT-PAD-ROUND2.5; 2,5-PAD-SIM
CAP-B: MOUNT-PAD-ROUND2.5; 2,5-PAD-SIM
D1: MBR120; SOD-123; MPN MBR120LSFT1G
D2: 1N4148; SOD-123
D3: RGBLED; PLCC4
DFU: TESTPOINTROUND2MM; TESTPOINT_ROUND_2MM
EN: CONN_021X02_NO_SILK; 1X02_NO_SILK
FRST: TESTPOINT1.5X2.0MM_NOCREAM; PAD-1.5X2.0
GPIO: CONN_041X04_NO_SILK; 1X04_NO_SILK
I2C: CONN_04_SIM1X04_NO_SILK; 1X04_NO_SILK_LNG
IO-2, IO-3: MOUNT-PAD-ROUND2.5; 2,5-PAD-SIM
J1: CONN_07; 1X07
L1: 10uH; L1210; MPN MF-IND-1210-10uH
M+: 1,6/0,8
M-: 1,6/0,8
Q1: DMG3415U-7; SOT23-R; MPN MF-DSC-SOT233-BSS84
R1, R2, R3, R4, R7, R11: 10K; R0603; MPN MF-RES-0603-10K
R5, R9, R10: 100K; R0603; MPN MF-RES-0603-100K
R6, R15: 330; R0603; MPN MF-RES-0603-330
R8: 1K; R0603; MPN MF-RES-0603-1K
R12: 27; R0603; MPN MF-RES-0603-27
R13, R14: 22; R0603; MPN MF-RES-0603-22
RESW: SWITCH_TACT_SMT4.6X2.8; BTN_KMR2_4.6X2.8
RST: TESTPOINTROUND2MM; TESTPOINT_ROUND_2MM
SJ1: AT; SOLDERJUMPER_CLOSEDWIRE
STAT: WHITE; LED0603; MPN LNJ037X8ARA
SW: SW; TACT4.2MM
SWCLK: TESTPOINTROUND2MM; TESTPOINT_ROUND_2MM
SWDIO: TESTPOINTROUND2MM; TESTPOINT_ROUND_2MM
SWO: TESTPOINTROUND2MM; TESTPOINT_ROUND_2MM
T2: MMBT3904; SOT-23-3
TOUCH: CONN_021X02_NO_SILK; 1X02_NO_SILK
U1: MDBT42Q; BLE_MODULE_RAYTAC_MDBT42; MPN 317030213
U2: AP2112; SOT23-5; MPN AP2112K-3.3TRG1
U3: ADXL345; LGA14-0.8-5.0X3.0MM
U4: CAP1188; QFN24_4MM_SMSC; MPN CAP1188-1-CP-TR
U5: DRV2605L; VSSOP-10; MPN DRV2605LDGST
X1: 32.768; XTAL3215; MPN ABS07-120-32.768KHZ-T

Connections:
3.3V: BUZZER.BZ+ (BUZSIG+), C2.P$1, C3.P$1, C5.P$1, C7.P$1, C9.P$1, D2.CATHODE, D3.P$1 (ANODE), GPIO.3, I2C.2, J1.2, R1.P$1, R2.P$1, R3.P$1, R8.P$1, R11.P$2, U1.11 (VDD), U2.5 (OUT), U3.1 (VDDI/O), U3.6 (VS), U3.7 (!CS), U4.23 (VDD), U5.P$5 (EN), U5.P$6 (VDD/NC), U5.P$10 (VDD)
BTN: SW.P$3, U1.18 (P0.05/AIN3)
BT_LED: R15.P$1, U1.33 (P0.19)
BUZZER: R7.P$2, T2.P$1 (BASE), U1.17 (P0.04/AIN2)
CAP-A: CAP-A.B2,8, TOUCH.1, U4.22 (CS1)
CAP-B: CAP-B.B2,8, TOUCH.2, U4.21 (CS2)
CAP-INT: R3.P$2, U1.5 (P0.28/AIN4), U4.13 (ALERT#/BC_IRQ#)
CAP-RES: R4.P$1, U1.6 (P0.29/AIN5), U4.24 (RESET)
DFU: DFU.P$1, U1.34 (P0.20)
DTR: C11.P$1, J1.5
EN: EN.1, R10.P$2, U2.3 (EN)
FRST: FRST.P$1, U1.38 (P0.22)
GND: B-.1, BTL.CATHODE, C1.P$2, C2.P$2, C3.P$2, C4.P$2, C5.P$2, C6.P$2, C7.P$2, C8.P$2, C9.P$2, C10.P$2, EN.2, GPIO.4, I2C.1, J1.3, R4.P$2, R5.P$2, R7.P$1, R9.P$2, RESW.B (S), RESW.B' (S1), STAT.CATHODE, SW.P$1, T2.P$2 (EMITTER), U1.1 (GND), U1.12 (GND), U1.24 (GND), U1.39 (GND), U2.2 (GND), U3.2 (GND), U3.4 (GND), U3.5 (GND), U4.1 (SPI_CS), U4.THERM (THERMAL/GND), U5.P$8 (GND)
IMU-INT: U1.20 (P0.07), U3.8 (INT1)
IO-2: GPIO.1, IO-2.B2,8, U1.15 (P0.02/AIN0)
IO-3: GPIO.2, IO-3.B2,8, U1.16 (P0.03/AIN1)
LED_B: R14.P$2, U1.25 (P0.11)
LED_G: R13.P$2, U1.29 (P0.15)
LED_R: R12.P$2, U1.30 (P0.16)
MISO: U1.28 (P0.14)
MOSI: U1.27 (P0.13)
unnamed: L1.P$2, U1.10 (DCC)
unnamed: C1.P$1, L1.P$1, U1.9 (DEC4)
unnamed: R5.P$1, U4.14 (ADDR_COMM)
unnamed: BUZZER.BZ- (BUZGND), R8.P$2, T2.P$3 (COLLECTOR)
unnamed: C6.P$1, U5.P$1 (REG)
unnamed: M-.1, U5.P$9 (OUT-)
unnamed: M+.1, U5.P$7 (OUT+)
unnamed: R6.P$2, STAT.ANODE
unnamed: C4.P$1, U1.13 (P0.00/XL1), X1.P$1
unnamed: C8.P$1, U1.14 (P0.01/XL2), X1.P$2
unnamed: C10.P$1, D1.C, Q1.2 (S), R10.P$1, U2.1 (IN)
unnamed: D3.P$2 (CATHODE_RED), R12.P$1
unnamed: D3.P$3 (CATHODE_GREEN), R13.P$1
unnamed: D3.P$4 (CATHODE_BLUE), R14.P$1
unnamed: BTL.ANODE, R15.P$2
unnamed: C11.P$2, SJ1.2
NFC1: U1.22 (P0.09)
NFC2: U1.23 (P0.10)
RESET: D2.ANODE, R11.P$1, RESW.A, RESW.A' (P1), RST.P$1, SJ1.1, U1.35 (P0.21/RESET)
RXD: J1.7, U1.21 (P0.08)
SCK: U1.26 (P0.12)
SCL: I2C.4, R1.P$2, U1.3 (P0.26), U3.14 (SCL/SCLK), U4.4 (SMCLK/BC_CLK/SPI_CLK), U5.P$2 (SCL)
SDA: I2C.3, R2.P$2, U1.2 (P0.25), U3.13 (SDA/SDI/SDIO), U4.3 (SMDATA/BC_DATA/SPI_MISO), U5.P$3 (SDA)
STATLED: R6.P$1, U1.7 (P0.30/AIN6)
SWCLK: SWCLK.P$1, U1.36 (SWDCLK)
SWDIO: SWDIO.P$1, U1.37 (SWDIO)
SWO: SWO.P$1, U1.32 (P0.18/SWO)
TXD: J1.6, U1.19 (P0.06)
VBAT: B+.1, J1.1, Q1.3 (D)
VBUS: D1.A, J1.4, Q1.1 (G), R9.P$1

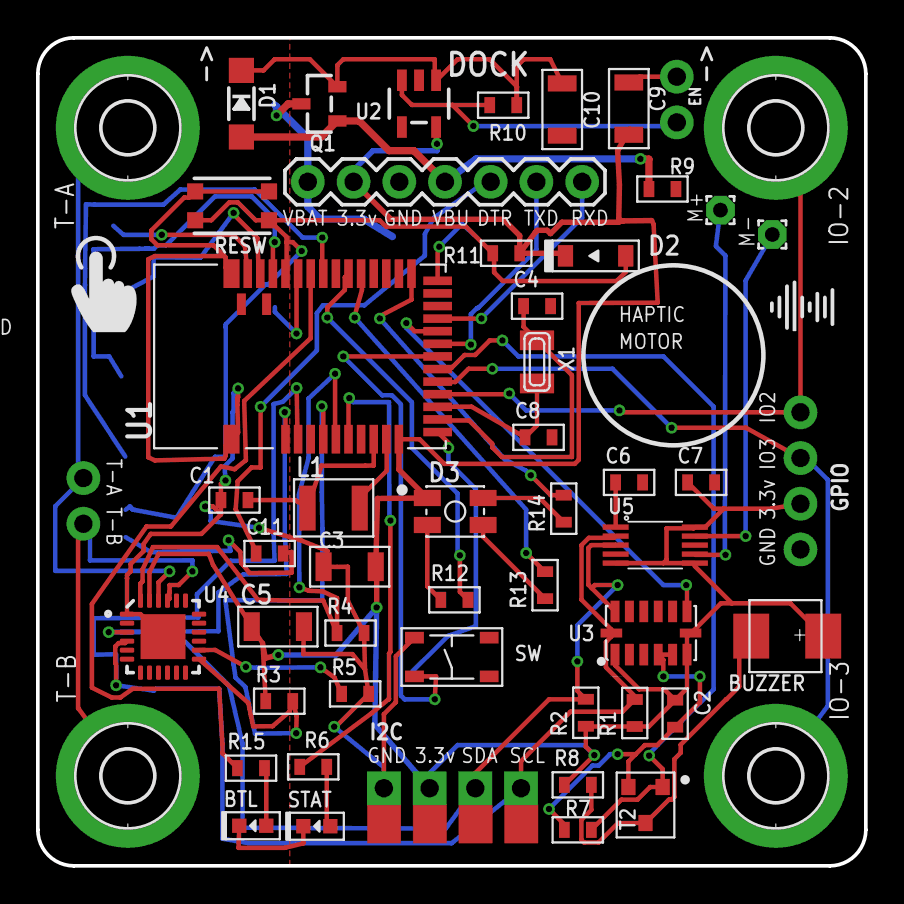
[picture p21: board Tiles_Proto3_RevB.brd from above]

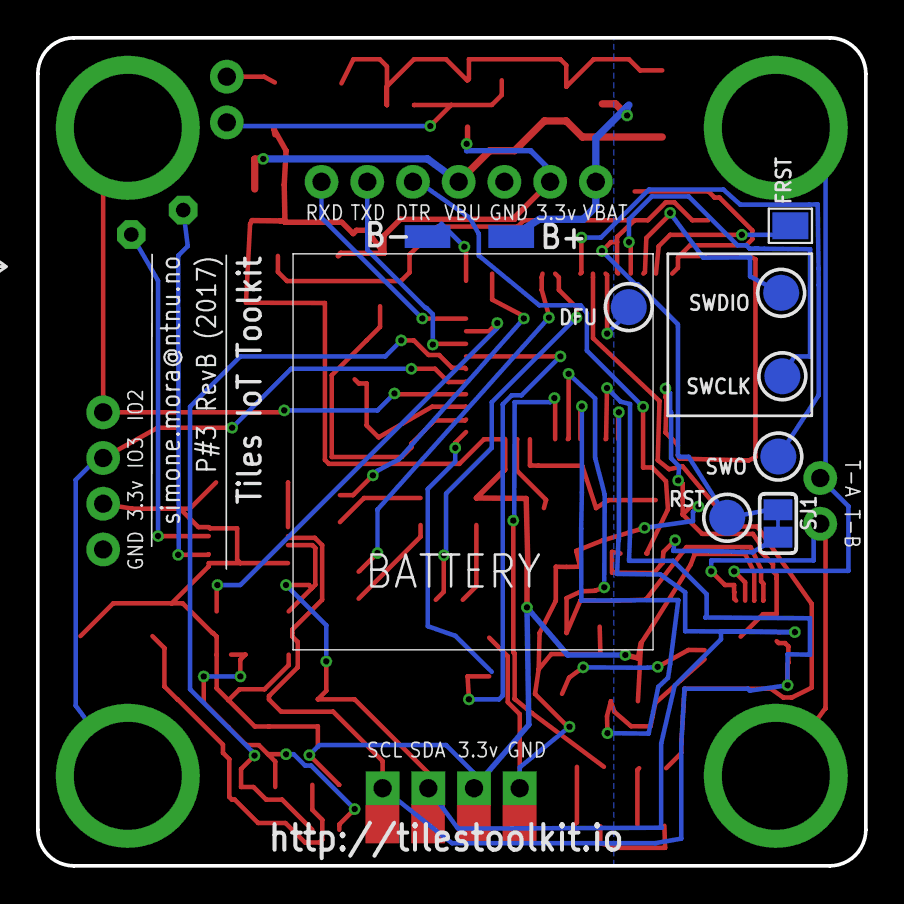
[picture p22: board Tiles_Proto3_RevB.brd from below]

Board: 2 copper layers, 46.0 x 46.0 mm, 63 parts (9 on the bottom side), 46 nets.

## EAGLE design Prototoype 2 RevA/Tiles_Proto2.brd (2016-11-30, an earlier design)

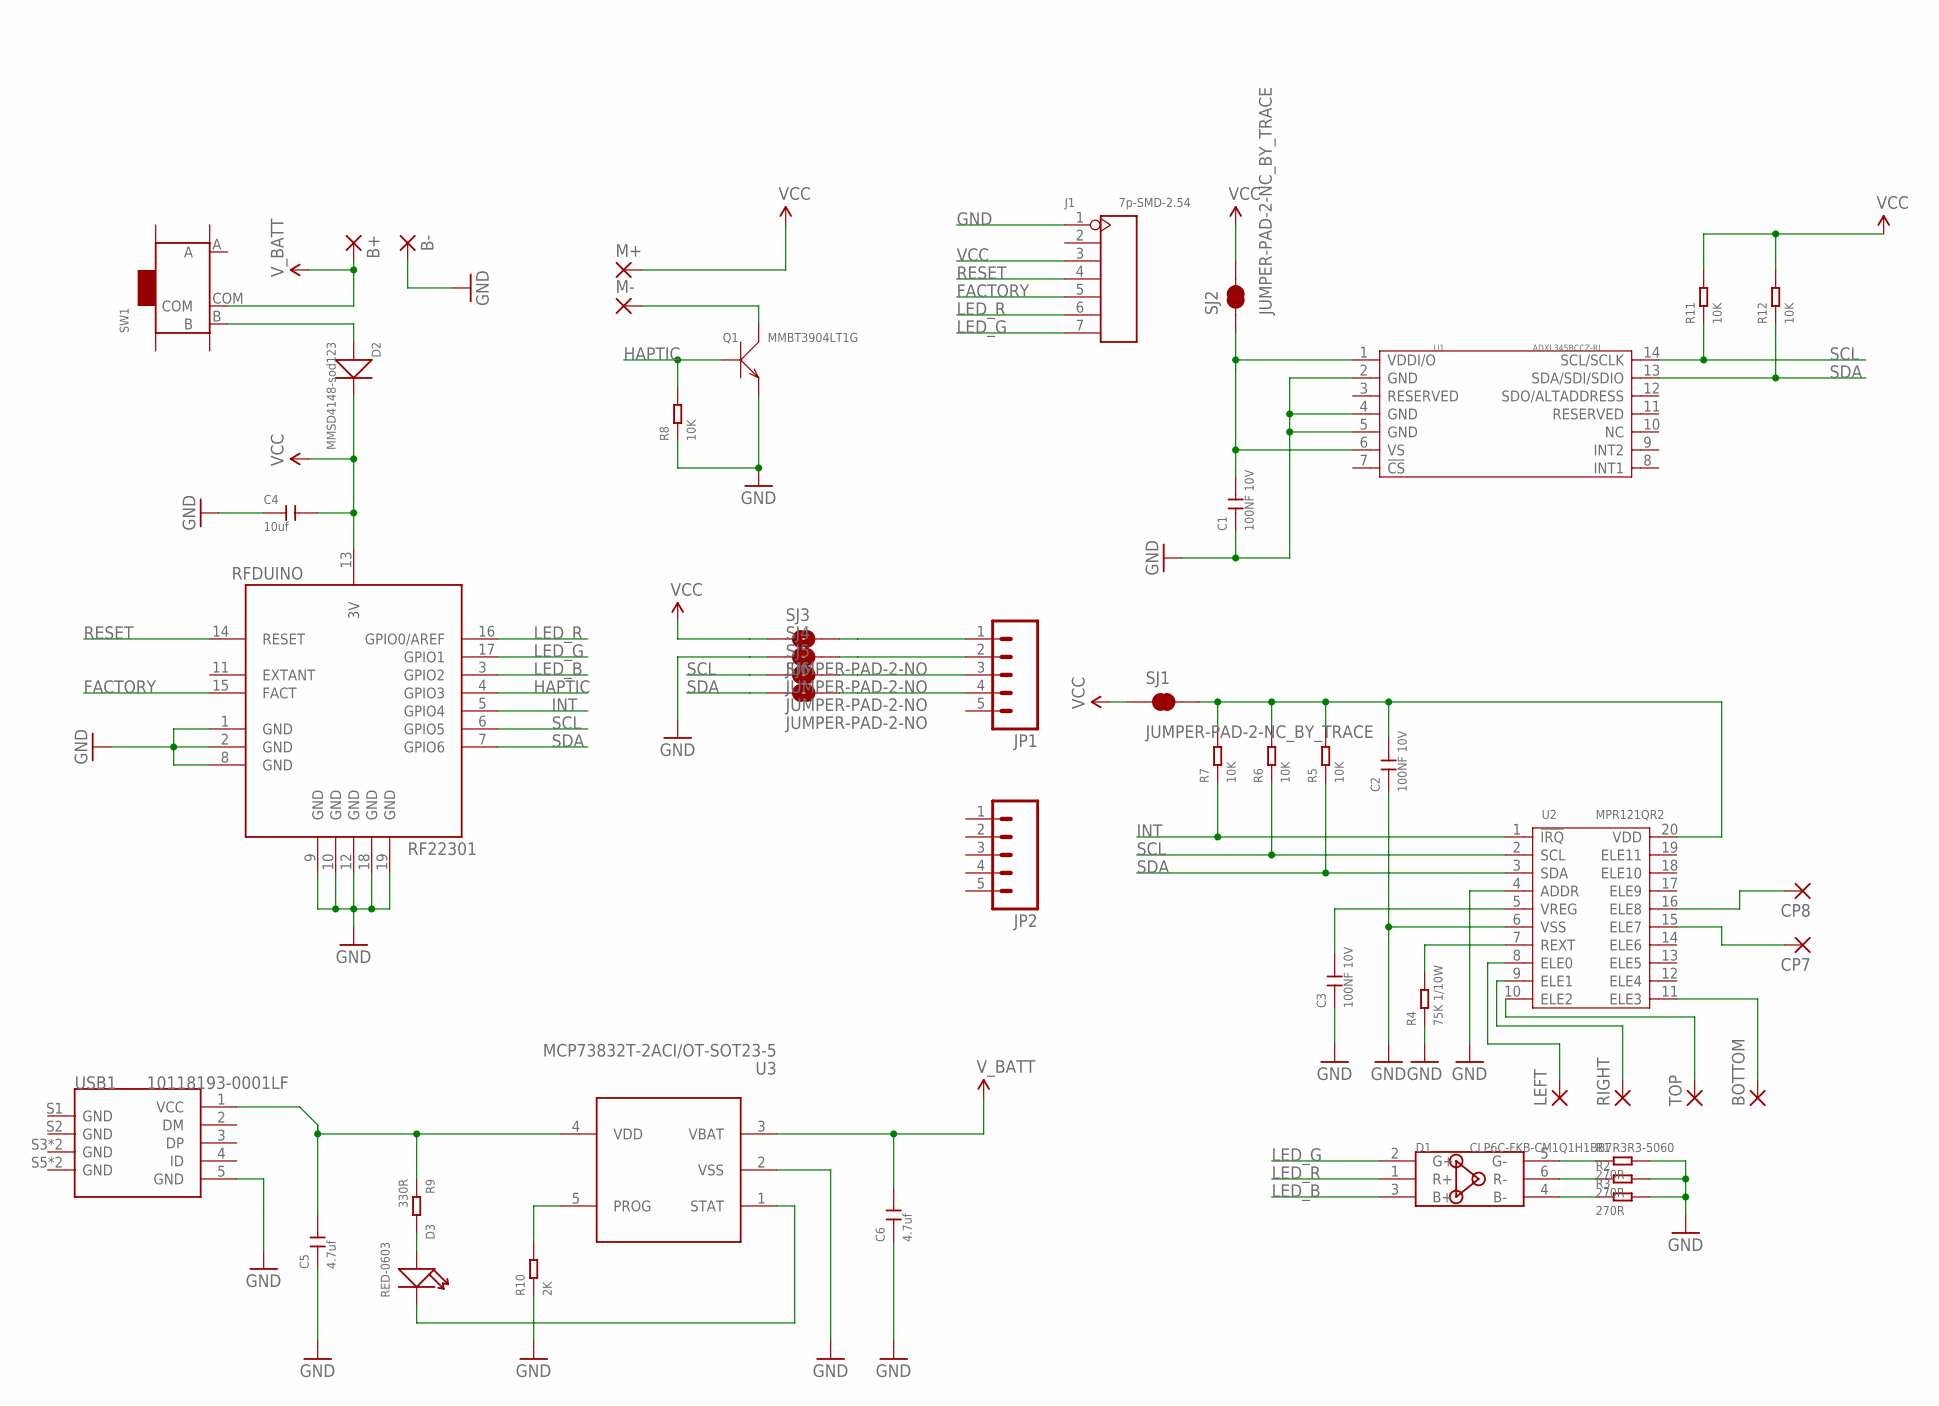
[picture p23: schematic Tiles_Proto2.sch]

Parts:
B+: SMD2; SMD1,27-2,54
B-: SMD2; SMD1,27-2,54
BOTTOM: SMD5; SMD2,54-5,08
C1, C2, C3: 100NF 10V; C0402
C4: 10uf; C0402
C5, C6: 4.7uf; C0402
CP7, CP8: SMD2; SMD1,27-2,54
D1: CLP6C-FKB-CM1Q1H1BB7R3R3-5060; LED6-SMD-5060
D2: MMSD4148-sod123; SOD-123
D3: RED-0603; LED-0603
J1: 7p-SMD-2.54; H7-SMD-2.54
JP1, JP2: M05PTH; 1X05
LEFT: SMD5; SMD2,54-5,08
M+: SMD2; SMD1,27-2,54
M-: SMD2; SMD1,27-2,54
Q1: MMBT3904LT1G; SOT-23
R1, R2, R3: 270R; R0805
R4: 75K 1/10W; R0603
R5, R6, R7, R8, R11, R12: 10K; R0603
R9: 330R; R0603
R10: 2K; R0603
RFDUINO: RF22301; RFD22301
RIGHT: SMD5; SMD2,54-5,08
SJ1, SJ2: JUMPER-PAD-2-NC_BY_TRACE; PAD-JUMPER-2-NC_BY_TRACE_YES_SILK
SJ3, SJ4, SJ5, SJ6: JUMPER-PAD-2-NO; PAD-JUMPER-2-NO_NO_SILK
SW1: SMD-TOGGLE-SWITCH-ON-ON(3+4P-6.7X2.7MM); SW7-SMD-L6.7X2.7X3.2MM
TOP: SMD5; SMD2,54-5,08
U1: ADXL345BCCZ-RL; LGA14-0.8-5.0X3.0MM
U2: MPR121QR2; QFN20-0.4-3X3M
U3: MCP73832T-2ACI/OT-SOT23-5; SOT-23-5
USB1: 10118193-0001LF; MICRO-USB5+6P-SMD-0.65-B

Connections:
FACTORY: J1.5, RFDUINO.15 (FACT)
GND: B-.1, C1.1, C2.1, C3.1, C4.1, C5.1, C6.1, J1.1, Q1.2 (E), R1.2, R2.2, R3.2, R4.1, R8.1, R10.1, RFDUINO.1 (GND), RFDUINO.2 (GND), RFDUINO.8 (GND), RFDUINO.9 (GND), RFDUINO.10 (GND), RFDUINO.12 (GND), RFDUINO.18 (GND), RFDUINO.19 (GND), SJ4.1, U1.2 (GND), U1.4 (GND), U1.5 (GND), U2.4 (ADDR), U2.6 (VSS), U3.2 (VSS), USB1.5 (GND)
HAPTIC: Q1.1 (B), R8.2, RFDUINO.4 (GPIO3)
INT: R7.1, RFDUINO.5 (GPIO4), U2.1 (!IRQ)
LED_B: D1.3 (B+), RFDUINO.3 (GPIO2)
LED_G: D1.2 (G+), J1.7, RFDUINO.17 (GPIO1)
LED_R: D1.1 (R+), J1.6, RFDUINO.16 (GPIO0/AREF)
unnamed: D1.5 (G-), R1.1
unnamed: D1.6 (R-), R2.1
unnamed: D1.4 (B-), R3.1
unnamed: C3.2, U2.5 (VREG)
unnamed: R4.2, U2.7 (REXT)
unnamed: JP1.1, SJ3.2
unnamed: M-.1, Q1.3 (C)
unnamed: C5.2, R9.1, U3.4 (VDD), USB1.1 (VCC)
unnamed: D2.+, SW1.B
unnamed: D3.+, R9.2
unnamed: D3.-, U3.1 (STAT)
unnamed: R10.2, U3.5 (PROG)
unnamed: JP1.2, SJ4.2
unnamed: JP1.3, SJ5.2
unnamed: JP1.4, SJ6.2
unnamed: LEFT.1, U2.8 (ELE0)
unnamed: RIGHT.1, U2.9 (ELE1)
unnamed: TOP.1, U2.10 (ELE2)
unnamed: BOTTOM.1, U2.11 (ELE3)
unnamed: CP7.1, U2.15 (ELE7)
unnamed: CP8.1, U2.16 (ELE8)
unnamed: C2.2, R5.2, R6.2, R7.2, SJ1.2, U2.20 (VDD)
RESET: J1.4, RFDUINO.14 (RESET)
SCL: R6.1, R11.1, RFDUINO.6 (GPIO5), SJ5.1, U1.14 (SCL/SCLK), U2.2 (SCL)
SDA: R5.1, R12.1, RFDUINO.7 (GPIO6), SJ6.1, U1.13 (SDA/SDI/SDIO), U2.3 (SDA)
VCC: C4.2, D2.-, J1.3, M+.1, R11.2, R12.2, RFDUINO.13 (3V), SJ1.1, SJ2.2, SJ3.1
VDDI/O: C1.2, SJ2.1, U1.1 (VDDI/O), U1.6 (VS)
V_BATT: B+.1, C6.2, SW1.COM, U3.3 (VBAT)

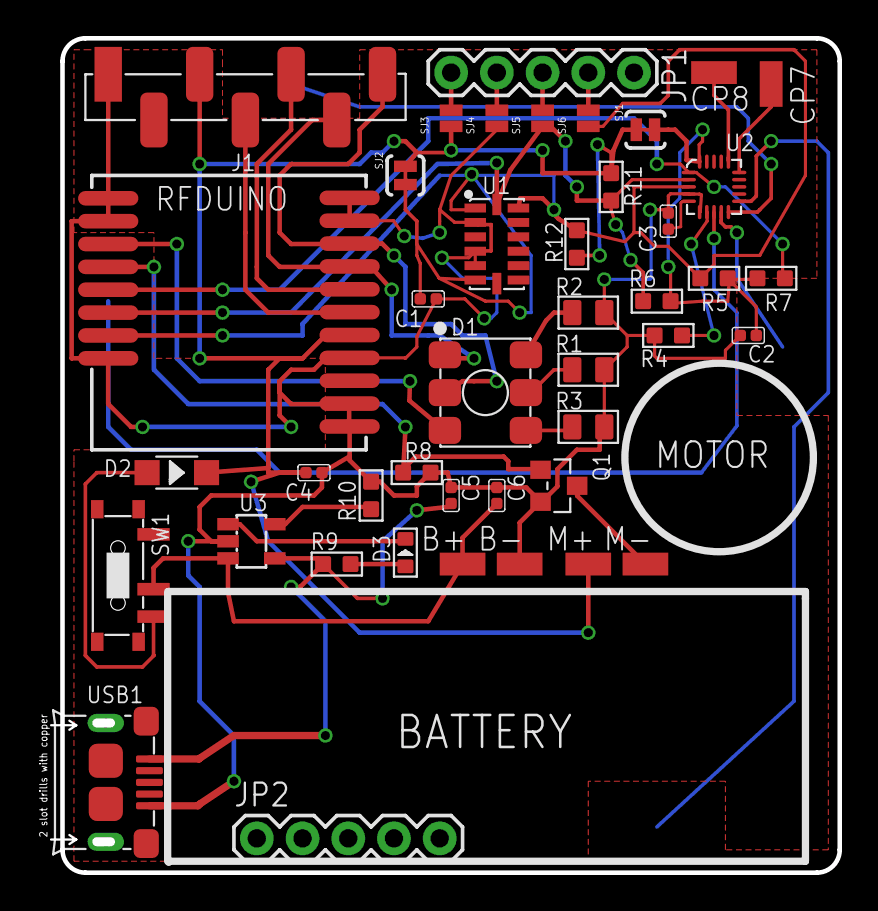
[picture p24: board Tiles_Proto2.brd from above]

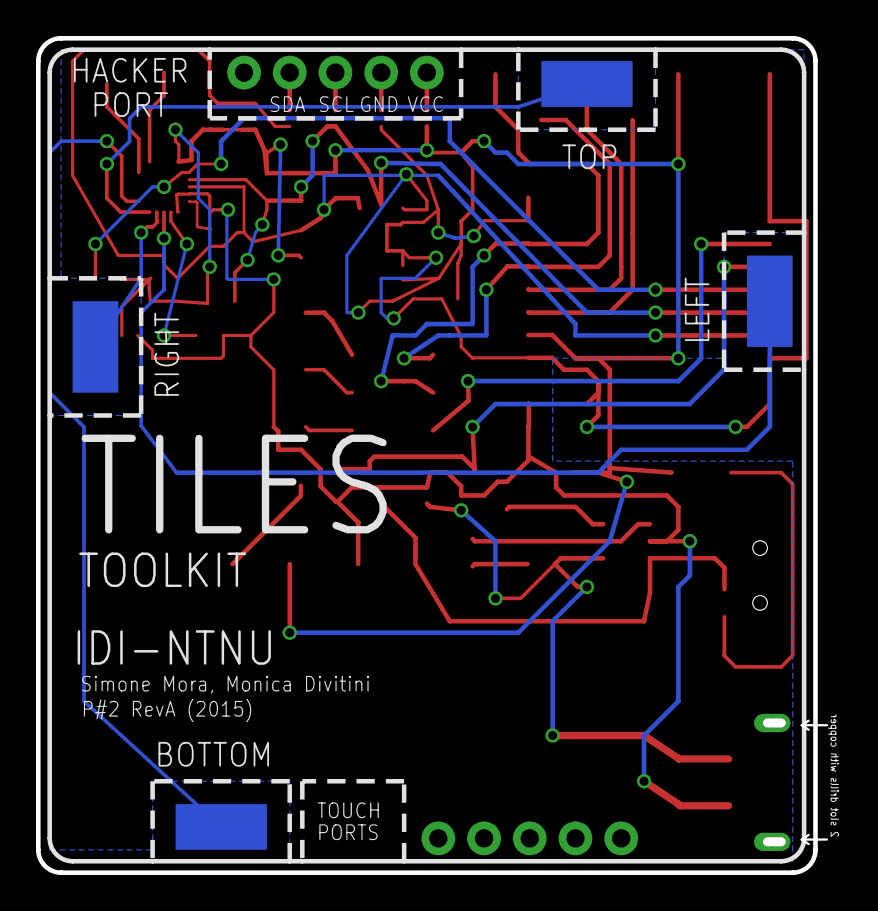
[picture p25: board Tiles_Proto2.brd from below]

Board: 2 copper layers, 43.8 x 46.4 mm, 47 parts (4 on the bottom side), 35 nets.

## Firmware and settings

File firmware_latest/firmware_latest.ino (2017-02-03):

/*
  TILES Test Led Button
  Example of how Bluetooth 4.0 communication. It works with custom-made button, red led, green led shield.
  HOWTOV01: Use a BT client to subscribe to characteristic 2221 events btnON, btnOFF. (tested with lightblue client on mac https://itunes.apple.com/us/app/lightblue)
  Green LED turns on when TILE is connecteed to a BT client.
  Red LED can be controlled by the client by sending the events "ledON" (or the HEX 0x01 as alternative) and "ledOFF" (or the HEX 0x00 as alternative).

  V.01 - 150915 - Simone Mora (simonem@ntnu.no)
  V.02 - 050215 - Simone Mora (simonem@ntnu.no)
  - added multiple event and command handling
  -RFDUINO LED BUTTON SHIELD VERSION-
*/

#include <RFduinoBLE.h>
#include <LEDFader.h>
#include <Wire.h>
//#include <WInterrupts.h>
#include <stdlib.h>

 #include <TokenSoloEvent.h>
//#include "libs/TS/TokenSoloEvent.h"
// Variables for Token Solo Event
volatile uint8_t intSource = 0; // byte with interrupt informations
adxl345_activity_t event;
int tab[] = {'0', '0'};
int single_tap = 0;
int double_tap = 0;
int shake = 0;
int inactivity = 0;
bool tilt = false;

#define is_shield true  // Used to define pins for RFduino shield or TILES Square

#if is_shield
#define RED_LED_PIN 2
#define GREEN_LED_PIN 3
#define BLUE_LED_PIN 4
#define VIBRO_PIN 0
#define ACC_INT1_PIN 1 // Pin where the acceleromter interrupt1 is connected
#else
#define RED_LED_PIN 0
#define GREEN_LED_PIN 1
#define BLUE_LED_PIN 2
#define VIBRO_PIN 3
#define ACC_INT1_PIN 4 // Pin where the acceleromter interrupt1 is connected
#endif

TokenSoloEvent tokenSolo = TokenSoloEvent(ACC_INT1_PIN); // Connected on pin 4
String event_name;
String payload;
char c_payload[19];

#define COMMON_ANODE

#define FADE_TIME 2000
#define DIR_UP 1
#define DIR_DOWN -1
LEDFader fade_red;
LEDFader fade_green;
LEDFader fade_blue;
int direction = DIR_UP;
bool fading = 0;

String adv_name;
String mac;
uint8_t *deviceADDR0 = (uint8_t *)0x100000a4; // location of MAC address last byte
char adv_name_c[8];

int interrupt_count = 0;

//COMMANDS
int ledState = LOW;                       // ledState used to set the LED
unsigned long previousMillis = 0;        // will store last time LED was updated
bool blinking = 0;
String blinkingColor;
String fadingColor;


int acc_event(uint32_t ulPin){
  uint8_t data = tokenSolo.accel.readRegister(ADXL345_REG_INT_SOURCE);

  if((data >> ADXL345_FREE_FALL) & 1){
    payload = adv_name + ",drop";
    payload.toCharArray(c_payload, 19);
    RFduinoBLE.send((char*) c_payload, 19);
    return 0;
  }

  if((data >> ADXL345_DOUBLE_TAP) & 1){
    payload = adv_name + ",tap,double";
    payload.toCharArray(c_payload, 19);
    RFduinoBLE.send((char*) c_payload, 19);
    return 0;
  }

  if((data >> ADXL345_SINGLE_TAP) & 1){
    payload = adv_name + ",tap,single";
    payload.toCharArray(c_payload, 19);
    RFduinoBLE.send((char*) c_payload, 19);
    return 0;
  }

}

void setup() {
  // Config of the accelerometer
  tokenSolo.accelConfig();

  //Define adv name
  mac = String(*deviceADDR0, HEX);
  adv_name = "Tile_" + mac;
  adv_name.toCharArray(adv_name_c, 8);

  //Setup IO PINs
  pinMode(GREEN_LED_PIN, OUTPUT);
  pinMode(RED_LED_PIN, OUTPUT);
  pinMode(BLUE_LED_PIN, OUTPUT);
  pinMode(VIBRO_PIN, OUTPUT);

  RFduino_pinWakeCallback(ACC_INT1_PIN, HIGH, acc_event);

  //blink the LEDS to test they are actually working
  digitalWrite(GREEN_LED_PIN, LOW);
  delay(250);
  digitalWrite(RED_LED_PIN, LOW);
  delay(250);
  digitalWrite(BLUE_LED_PIN, LOW);
  delay(500);
  digitalWrite(GREEN_LED_PIN, HIGH);
  digitalWrite(RED_LED_PIN, HIGH);
  digitalWrite(BLUE_LED_PIN, HIGH);

  //Setup Bluetooth Connectivity
  //set the device name
  RFduinoBLE.deviceName = adv_name_c;
  //set the data we want to appear in the advertisement (max 31bytes)
  RFduinoBLE.advertisementData = adv_name_c;
  //set advertising interval in ms (low-longer battery life)
  RFduinoBLE.advertisementInterval = 200;
  //set tx signal strenght (value between -30 and +4dDm in 4dBm increments)
  RFduinoBLE.txPowerLevel = -20;
  //start the BLE stack
  RFduinoBLE.begin();

  fade_red = LEDFader(RED_LED_PIN);
  fade_green = LEDFader(GREEN_LED_PIN);
  fade_blue = LEDFader(BLUE_LED_PIN);
}


void loop() {
  /************************************************************/

  if (abs(tokenSolo.accelGetX()) > 7 || abs(tokenSolo.accelGetY()) > 7){
    payload = adv_name + ",tilt";
    payload.toCharArray(c_payload, 19);
    RFduinoBLE.send((char*) c_payload, 19);
  }

  if (inactivity)
  {
    //tokenConstraint.rgb_sensor.getData();
  }

  if (blinking)
    blink(blinkingColor);

  if (fading) {
    fade(fadingColor);
  }

//  delay(500); // Important delay, do not delete it !
  RFduino_ULPDelay(1000);
}

void RFduinoBLE_onConnect()
{
  digitalWrite(GREEN_LED_PIN, HIGH);
  delay(500);
  digitalWrite(GREEN_LED_PIN, LOW);
}

void RFduinoBLE_onDisconnect()
{
  digitalWrite(GREEN_LED_PIN, LOW);
}

void RFduinoBLE_onAdvertisement() {
  digitalWrite(RED_LED_PIN, HIGH);
}

//Callback when a data chunk is received. OBS! Data chunks must be 20KB (=20 ASCII characters) maximum!
void RFduinoBLE_onReceive(char *data, int len)
{
  //TODO verify whether the payload variable has to be deallocated to avoid memory leaks
  // char payload[6];
  // strncpy(payload,data,len);

  //debugging data packet received
//  Serial.println("Data received");
//  Serial.print("Packet lenght: "); Serial.println(len);
//  Serial.print("Payload: "); Serial.println(data);

  String command;
  command = data;
  command = command.substring(0, len);

  int commaIndex = command.indexOf(',');
  //  Search for the next comma just after the first
  int secondCommaIndex = command.indexOf(',', commaIndex + 1);

  String firstValue = command.substring(0, commaIndex);
  String secondValue = command.substring(commaIndex + 1, secondCommaIndex);
  String thirdValue = command.substring(secondCommaIndex + 1);

//  Serial.print("Command: "); Serial.println(command);
//  Serial.print("FirstValue: "); Serial.println(firstValue);
//  Serial.print("SecondValue: "); Serial.println(secondValue);
//  Serial.print("ThirdValue: "); Serial.println(thirdValue);

  if (firstValue == "led") {
    if (secondValue == "off") {
      blinking = 0;
      fading = 0;
      setColor("off");
    }
    else if (secondValue == "on")
    {
      blinking = 0;
      fading = 0;
      setColor(thirdValue);
    }
    else if (secondValue == "blink")
    {
      fading = 0;
      blinking = 1;
      blinkingColor = thirdValue;
    }
    else if (secondValue == "fade") {
      blinking = 0;
      fading = 1;
      fadingColor = thirdValue;
    }
  }
  else if (firstValue == "haptic") {
    if (secondValue == "long") {
      haptic("long");
    } else if (secondValue == "burst") {
      haptic("burst");
    }
  }
}

// LED Functions
void setColor(String color)
{
  if (color == "off")
    setColorRGB(0, 0, 0);
  else if (color == "red")
    setColorRGB(255, 0, 0);
  else if (color == "green")
    setColorRGB(0, 255, 0);
  else if (color == "blue")
    setColorRGB(0, 0, 255);
  else if (color == "white")
    setColorRGB(255, 255, 255);
  else if (color.length() == 6) {
    int red, green, blue;
    parseColorString(color, red, green, blue);
    setColorRGB(red, green, blue);
  }
}

void parseColorString(String color, int& red, int& green, int& blue) {
  unsigned int colorHex = strtol(&color[0], NULL, 16);
  red = (int)((colorHex >> 16) & 0xFF);  // Extract the RR byte
  green = (int)((colorHex >> 8) & 0xFF); // Extract the GG byte
  blue = (int)((colorHex) & 0xFF);       // Extract the BB byte
}


void setColorRGB(int red, int green, int blue)
{
#ifdef COMMON_ANODE
  red = 255 - red;
  green = 255 - green;
  blue = 255 - blue;
#endif
  analogWrite(RED_LED_PIN, red);
  analogWrite(GREEN_LED_PIN, green);
  analogWrite(BLUE_LED_PIN, blue);
}

void blink(String color)
{
  unsigned long currentMillis = millis();
  if (currentMillis - previousMillis >= 500) {
    // save the last time you blinked the LED
    previousMillis = currentMillis;
    // if the LED is off turn it on and vice-versa:
    if (ledState == LOW) {
      ledState = HIGH;
    } else {
      ledState = LOW;
    }
    // set the LED with the ledState of the variable:
    if (ledState == LOW)
      setColor("off");
    else
      setColor(color);
  }
}

void haptic(String pattern)
{
  if (pattern == "long")
  {
    digitalWrite(VIBRO_PIN, HIGH);
    delay(1500);
    digitalWrite(VIBRO_PIN, LOW);
  }
  else if (pattern == "burst") {
    for (int i = 0; i < 4; i++)
    {
      digitalWrite(VIBRO_PIN, HIGH);
      delay(150);
      digitalWrite(VIBRO_PIN, LOW);
      delay(150);
    }
  }
}

void fade(String color) {
  fade_blue.update();
  // LED no longer fading, switch direction
  if (!fade_blue.is_fading()) {
    // Fade down
    if (direction == DIR_UP) {
      fade_blue.fade(0, FADE_TIME);
      direction = DIR_DOWN;
    }
    // Fade up
    else {
      fade_blue.fade(255, FADE_TIME);
      direction = DIR_UP;
    }
  }
}

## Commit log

2015-11-05 Tiles SCH first draft
    [Tiles_Proto2.sch]
2015-11-05 first draft board
    [Tiles_Proto2.brd, Tiles_Proto2.sch]
2015-11-09 version before starting routing
    [Tiles_Proto2.brd, Tiles_Proto2.sch]
2015-11-09 routing in progress
    [Tiles_Proto2.brd, Tiles_Proto2.sch]
2015-11-17 finished routing, no silk screen
    [Tiles_Proto2.brd]
2015-11-17 top silskreen
    [Tiles_Proto2.brd]
2015-11-17 finished silkscreen, no copper pour
    [Tiles_Proto2.GBL, Tiles_Proto2.GBO, Tiles_Proto2.GBP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]
2015-11-18 added BOM
    [TILES_PROTO2_BOM_SEEED.csv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]
2015-11-19 fixed 6 pins header
    [BOM_COMPLETE.xlsx, TILES_PROTO2_BOM_SEEED.csv, Tiles_Proto2.sch]
2015-11-20 before copper pour
    [Tiles_Proto2.brd]
2015-11-20 ready for production
    [Tiles_Proto2.brd]
2016-02-12 Start of Proto2RevB
    [Adafruit_ADXL345.brd, Adafruit_ADXL345.sch, BOM_COMPLETE.xlsx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]
2017-02-05 added LED brightness variable
2017-02-27 minor fix
    [BOM_COMPLETE.xlsx]
2017-03-15 added tiles printer code
2017-03-22 added LED extension
2017-03-22 LED extension working copy
2017-04-06 added tiles printer construction box
2017-04-06 updated to eagle 8
    [Tiles_Proto2_RevD.brd]
2017-04-25 fw beta
    [Neopixel ring case.stl]
2017-05-06 added pics square LED extension
2017-05-06 prototype 3 hw initiated
    [Tiles_Proto3_RevA.brd, Tiles_Proto3_RevA.sch]
2017-05-18 proto#3 schematics created
    [Tiles_Proto3_RevA.sch]
2017-05-18 encapsulated LED logic
2017-05-22 routing finshed
    [Tiles_Proto3_RevA.brd, Tiles_Proto3_RevA.sch]
2017-05-22 finished cleanup
    [Tiles_Proto3_RevA.brd, Tiles_Proto3_RevA.sch]
2017-05-22 added text
    [Tiles_Proto3_RevA.brd, Tiles_Proto3_RevA.sch]
2017-05-23 finished silkscreen
    [Tiles_Proto3_RevA.brd, Tiles_Proto3_RevA.sch]
2017-05-23 silkscreen update
    [Tiles_Proto3_RevA.brd]
2017-05-24 added tiles dock
    [Dock P1RA.brd, Dock P1RA.sch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]
2017-05-24 increased holes to 3mm
    [Dock P1RA.brd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]
2017-05-24 candidate p3 and dock
    [Dock P1RA.brd, Dock P1RA.sch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]
2017-05-25 dock and p3 ready for production
    [Dock P1RA.GBL, Dock P1RA.GBO, Dock P1RA.GBP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]
2017-05-26 switched imu from LSM9DS1 to ADXL345
    [Dock P1RA.brd, Dock P1RA.sch, Tiles_Proto3_RevA.brd]
2017-05-29 p3rA and dock p1rA sent to production
    [Dock P1RA.GBL, Dock P1RA.GBO, Dock P1RA.GBP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]
2017-05-29 updated bom
    [P#3RA-BOM.xlsx]
2017-09-26 removed firmware code
    [Neopixel ring case.stl, P#3RA-BOM.xlsx]
2017-10-04 BOM update
    [P#3RA-BOM-NOCA.xlsx, P#3RA-BOM.xlsx, Tiles_Proto3_RevA.brd]
2017-11-14 added proto 3 Rev B
    [P#3RA-BOM-NOCA.xlsx, P#3RA-BOM.xlsx, Tiles_Proto2_RevD.sch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]
2017-11-16 finished placing proto3revB
    [Tiles_Proto3_RevB.brd, Tiles_Proto3_RevB.sch]
2017-11-16 partial routing
    [Tiles_Proto3_RevB.brd, Tiles_Proto3_RevB.sch]
2017-11-17 ready for prod
    [Tiles_Proto3_RevB.brd, Tiles_Proto3_RevB.sch]
2017-11-20 added dock p1rb
    [Dock P1RB.brd, Dock P1RB.sch, Tiles_Proto3_RevB.brd]
2017-11-20 values back in sch
    [Tiles_Proto3_RevB.brd, Tiles_Proto3_RevB.sch]
2017-11-21 re-added part values
    [Tiles_Proto3_RevB.brd, Tiles_Proto3_RevB.sch]
2017-11-21 ready for ready for prod
    [Tiles_Proto3_RevB.brd]
2017-11-22 sent to production
    [Tiles_Proto3_RevB.brd]
2017-11-22 dock ready for prod
    [Dock P1RB.brd, Dock P1RB.sch, Tiles_Proto3_RevB_aggregate.csv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]

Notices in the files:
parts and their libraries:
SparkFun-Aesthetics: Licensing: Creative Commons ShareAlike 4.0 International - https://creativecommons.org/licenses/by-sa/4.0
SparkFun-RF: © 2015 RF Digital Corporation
